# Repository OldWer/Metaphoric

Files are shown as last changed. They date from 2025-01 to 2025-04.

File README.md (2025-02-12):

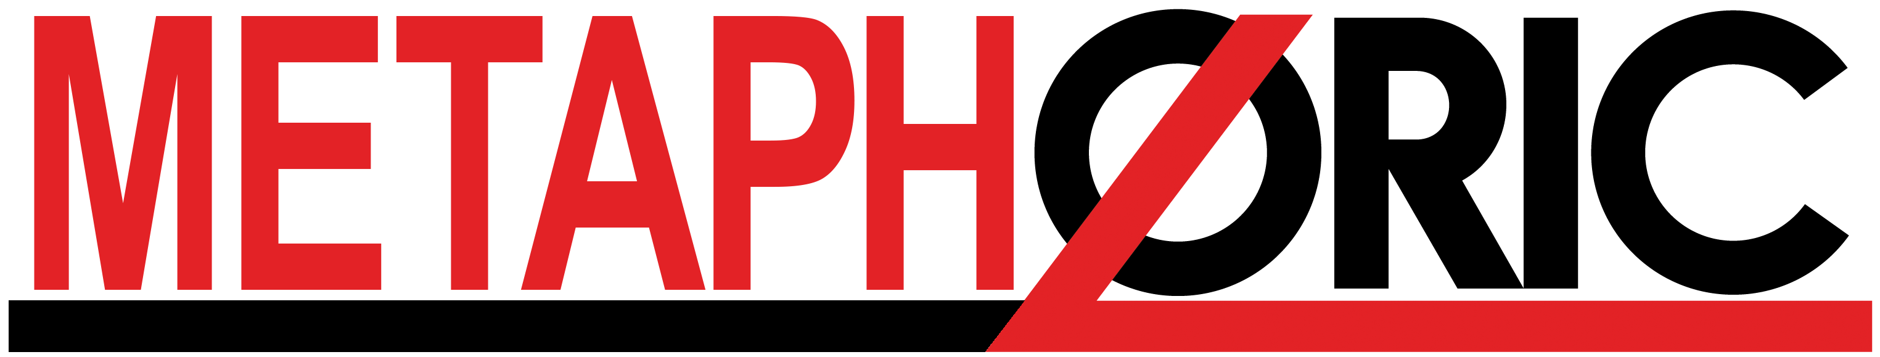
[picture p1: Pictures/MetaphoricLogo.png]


# Metaphoric - an enhanced Oric clone
Metaphoric is an Oric clone with the memory subsystem based on the OriClone-1 project and some additional features:
* Composite video output (RCA socket)
* TRRS audio-video socket for connecting "jack to 3xRCA" cable
* Footprints for both original AY-3-8912 chips and for (much cheaper) AY-3-8910 chips (or other 40-pin clones)
* Ability to use 7905 or 7805 power regulator and also to power the Metaphoric using an external +5V power supply
* Two Atari-standard joystick ports on the keyboard PCB — one is an IJK „Stingy” port, the other is a cursors+space joystick for games that do not support IJK but are controlled with cursors or make it possible to redefine the keys.
* Easily accessible RESET and NMI buttons on top of the keyboard.
* Easily accessible switches for changing the ROM between Oric-1 and Oric Atmos and for disabling the IJK interface (it may interfere with the operation of printer port and it can also corrupt sound in games that do not support IJK, e.g. Manic Miner)
* Automatic hardware V-sync hack - original Orics did not have any way of checking the vertical sync signal, which made it difficult to write games without flickering sprites, so somebody came up with the idea of connecting video sync signal to tape in using an external cable and synchronizing games/demos in that way. Metaphoric has a transistor that connects sync out to tape in when the tape relay is inactive and disconnects it when the relay is active (to allow loading from tape).

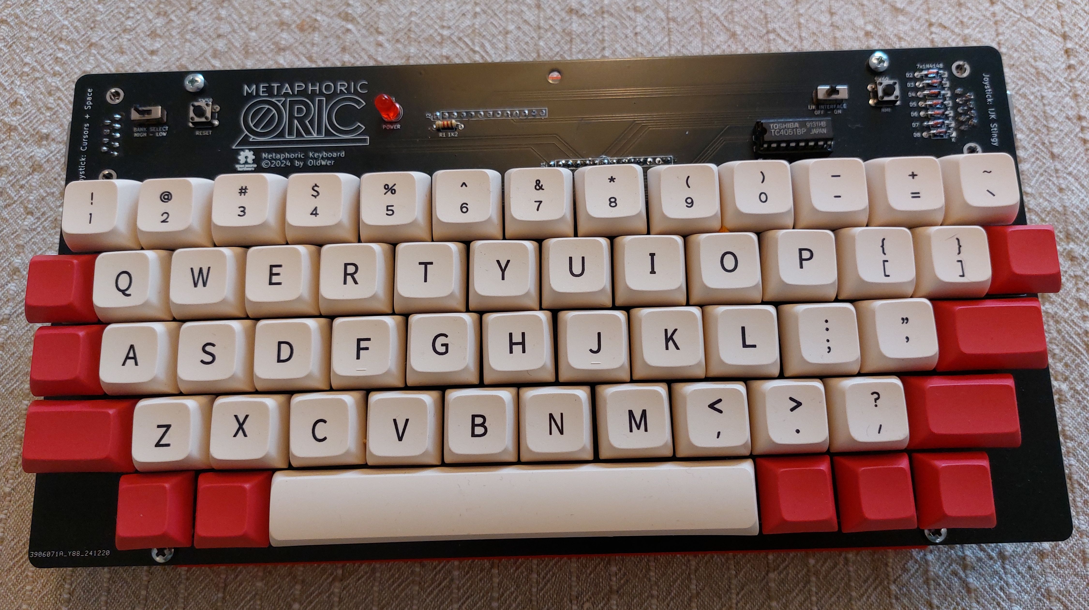
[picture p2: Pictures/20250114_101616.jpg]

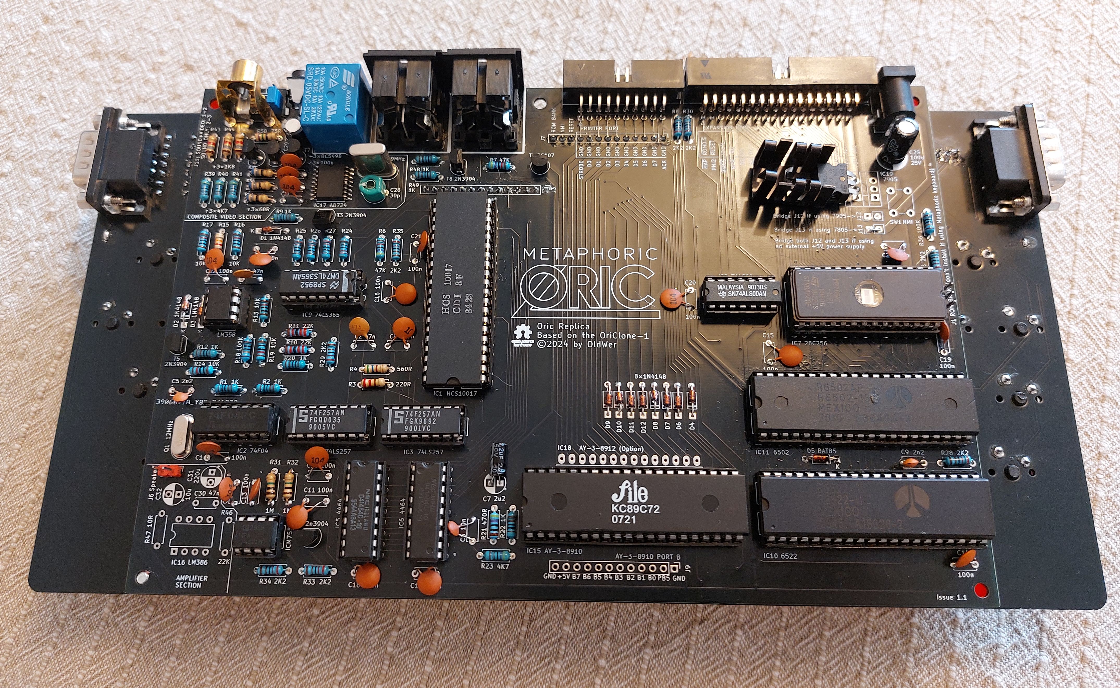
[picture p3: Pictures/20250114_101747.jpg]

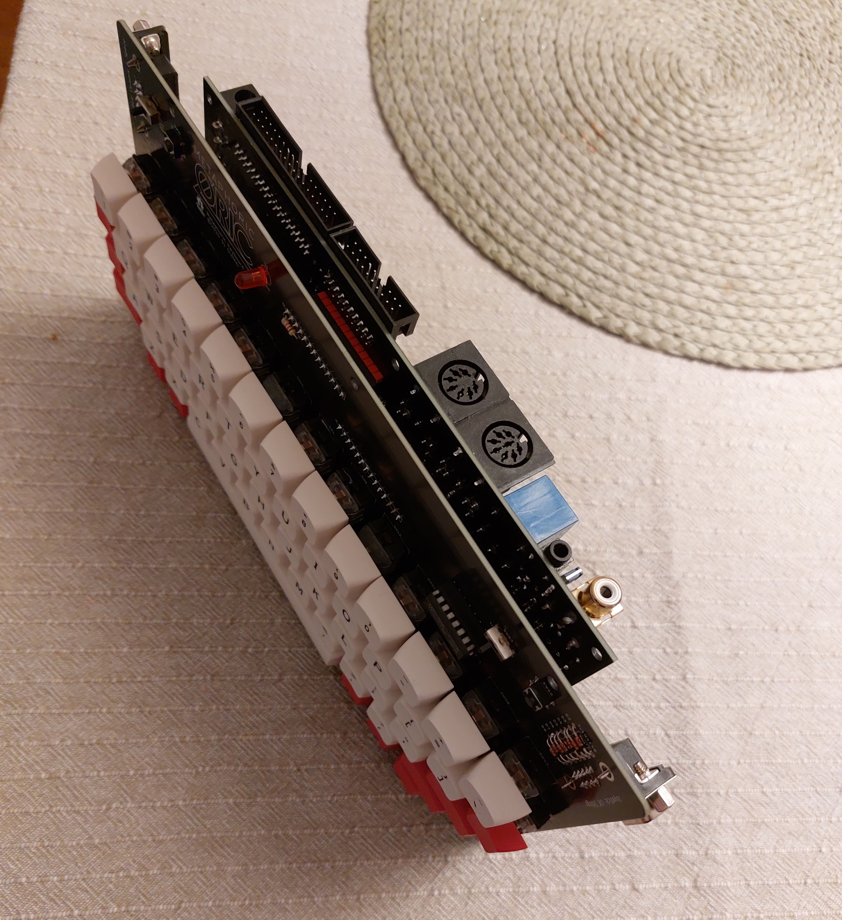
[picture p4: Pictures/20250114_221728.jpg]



# Building the Metaphoric
<b>Note</b>: The main PCB fits in the original Oric-1/Atmos case (the keyboard PCB <i>does not</i>!). If you would like to use the main PCB with the original keyboard and case, do not install J10 (TRRS socket) and J7 (auxiliary connector that supports the extra switches, buttons and ports on the keyboard). Also all the chips near the bottom of the board - IC10, IC15/18, IC5, IC6, IC12 and IC16 - cannot be socketed and must be soldered directly to the board, or the original case won't close.

The repository contains two directories with KiCAD projects for the main PCB and the keyboard PCB. The bill of materials is available in <i>BOM.*</i> files in the respective directories (in <i>.csv</i>, <i>.xlsx</i> and <i>.PDF</i> formats). In the <i>gerbers</i> subdirectories there are gerber files ready for manufacturing (I used recommended JLCPCB settings when exporting the gerbers). In the main PCB's <i>STL</i> subdirectory there are 3D models for a simple case and also for a spacer which you can print in 5 copies and which is used to separate the two boards. In the keyboard's <i>STL</i> subdirectory there is a 3D model for a holder that fits in the big square holes in the keyboard PCB and holds a typical space key stabilizer.

<b>Note about ROMs</b>: You can use either a 28c128 EEPROM or a 27c512 EPROM, appropriate <i>.bin</i> files are in the <i>MetaphoricV2/ROM</i> subdirectory. 27c256 EPROM would be enough to store two 16K banks with Oric-1 and Atmos ROMs, but it has different pinout - it would still work, but it wouldn't be possible to select ROM banks and only the high bank would be available. However, if you happen to have only 27c256 EPROMs, you may cut the trace between the ROM pins 27 and 28 (on the back of the PCB) and run a bodge wire from ROM pin 1 to ROM pin 27; this should make it possible to use a 27c256 EPROM with switchable banks.

Most of the build is pretty self-explanatory, as all the components are described on the PCB. The things to watch for, in no particular order, are as follows:
1. You can omit all the parts in the 'COMPOSITE VIDEO SECTION' if you're only planning to use the RGB output (well, maybe except for the TRRS socket, which can also be used to output audio, and the J11 header). The file 'RGB_Scart_Tape.pdf' shows how to build a SCART cable, and this is definitely the recommended way of using an Oric, original or cloned.
2. Next to the composite RCA socket there is the J11 header. You can put jumper on pins 2-3 to use the nearby 3.5mm TRRS socket as an audio/video video out; there are ready-made 3.5mm jack-3 x RCA cables which you can use to output video and sound. Or you can put a jumper on pins 1-2 to use the TRRS socket as a regular 3.5mm stereo sound out, useful for connecting the Oric to a stereo system or an external speaker. 
3. You can omit all the parts in the "AMPLIFIER SECTION" if you're not going to use the internal speaker. Again, highly recommended to skip these components, they were only added for the sake of completeness, the sound quality is pretty terrible with the internal speaker and in some games there is no way to turn it off or to control volume.
4. The J1 header on the right side of the board can be used to switch the ROM bank, but if the main PCB is connected to the Metaphoric keyboard PCB, it <b>should not</b> be jumpered. There is a switch on the keyboard PCB that does the same, and because switching the banks means connecting either ground or +5V to one of the ROM address lines, if you leave the J1 jumpered and then connect the Metaphoric keyboard, in one of the two switch positions the +5V will get shorted to ground. So you can install the J1 e.g. for testing the main PCB or if it is to be used in the original Oric case, but before you connect it to the Metaphoric keyboard, <b>remember to take the jumper off!</b>
5. In the power section in the top right corner of the main PCB there are footprints for either 7905 or 7805 regulator. The 7905 is recommended only if you intend to use the Metaphoric with original Oric accessories, such as floppy drives (or modern recreations, such as Cumana Reborn). Modern solutions, such as Erebus or Loci, can be used with 7805 or an external +5V power supply. Depending on which regulator you choose, you must close one of the J12/J13 bridges. Close J12 (using a piece of wire, a diode leg will do) if using 7905, close J13 if using 7805. It is also possible to connect an external power switch across one of those bridges and use it to power the Metaphoric on and off. Another way to power the Metaphoric is to close both J12 and J13 bridges (without installing any regulator!) and use external +5V power supply, <b>center positive</b> (ground on the sleeve, +5V on the tip). I personally prefer this solution (no heat generated inside) and just use a USB power supply. If you decide to use a regulator, power the Metaphoric with a +9V power supply, <b>center positive</b>.
9. The main PCB and the keyboard PCB are connected using two pin headers - J3 and J7 on the main PCB, J1 and J2 on the keyboard PCB. Two male pin headers must be installed on the back of the main PCB, two female headers on the back of the keyboard PCB, and then the two boards must be connected back to back:
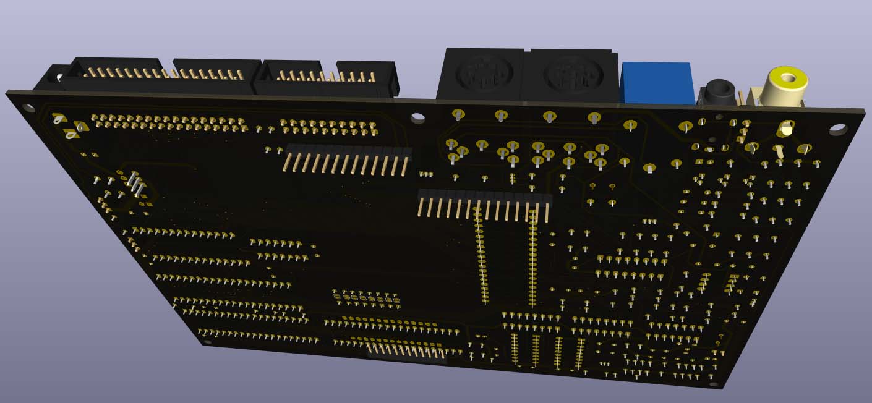
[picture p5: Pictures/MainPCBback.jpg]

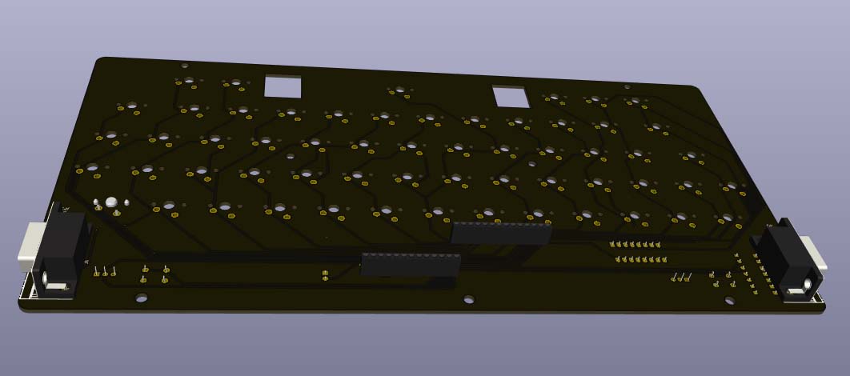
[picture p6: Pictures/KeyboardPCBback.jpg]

Then you should put 3D printed spacers between the two boards where the holes are and screw the boards to the case using M3x16 or M3x18 screws.

10. As for the keyboard, the joystick ports must be soldered on the back side of the PCB, like so:
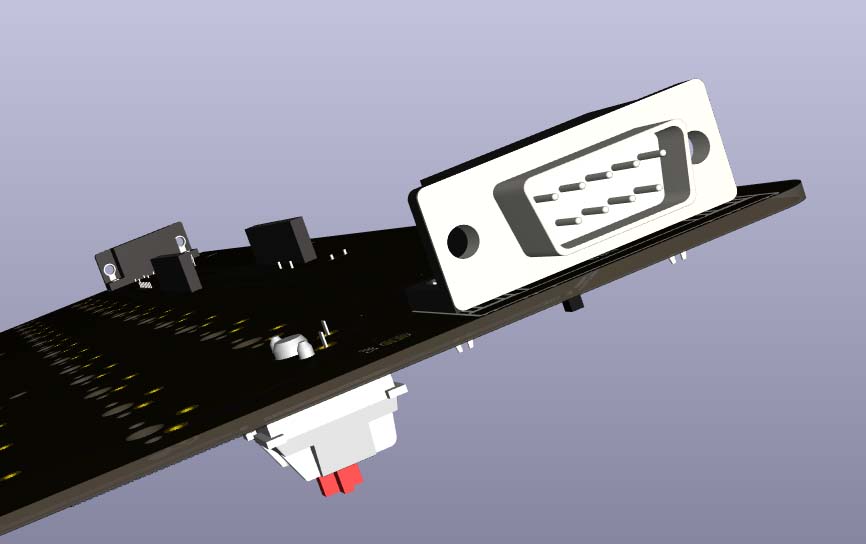
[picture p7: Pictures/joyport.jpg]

11. There are also solder jumpers JP2 and JP3 that can be used to configure additional joystick buttons (as in eg. MSX, Amstrad CPC or Sega Master System/Amiga joysticks). There are some powered joysticks (e.g. with an autofire function) which are usually powered from the pin 7 of the DB9 port, and it probably wouldn't be a good idea to power them intermittently from the outputs of the VIA or the AY chip. If you'd like to use additional buttons, see the note in the keyboard schematic.
12. The spacebar stabilizer holder must be printed once in normal orientation (left) and once mirrored (right), because it is not exactly symmetrical. Then the holders must be pushed into the big square holes in the kyeboard PCB (some light sanding may be necessary), and finally the stabilizer itself must be glued to the holders with a tiny amount of glue (so as not to glue together the moving plastic parts).
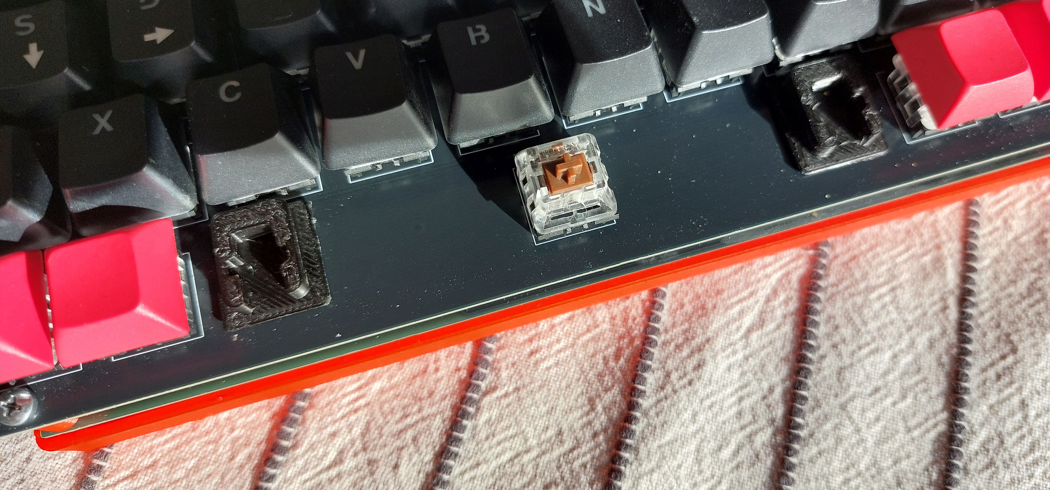
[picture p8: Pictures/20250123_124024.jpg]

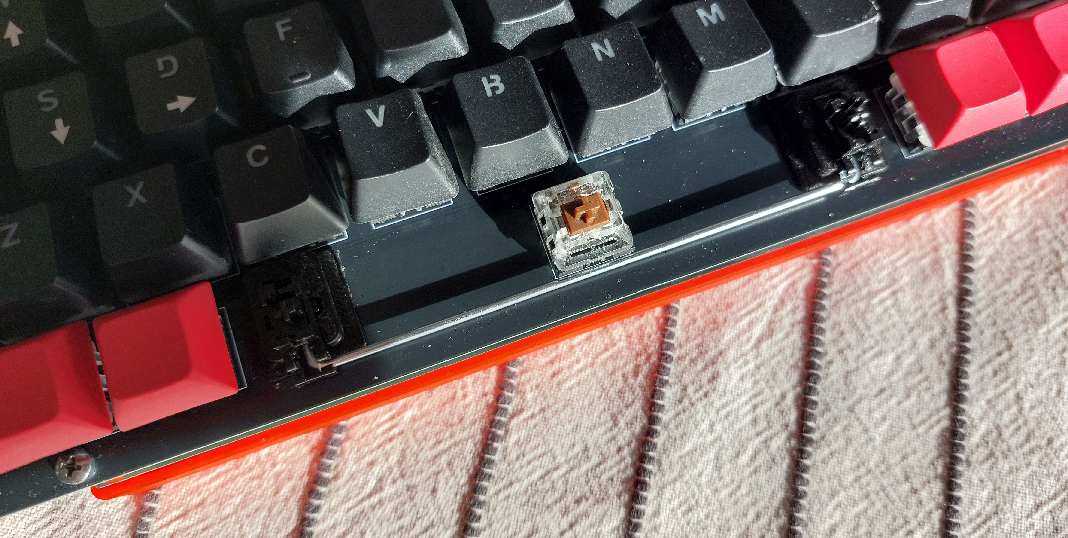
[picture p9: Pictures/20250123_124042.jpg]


If in doubt, open the relevant KiCAD PCB file and go to the 3D viewer; I've added 3D models for all the parts, creating some that I could not find anywhere, and you can check exactly how everything should look like.

If you have any questions, write to me at oldwer@op.pl, I will be happy to help.

Good luck soldering your own Oric!

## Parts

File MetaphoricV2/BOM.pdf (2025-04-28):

Reference | Value | Footprint | Qty | Notes
CAPACITORS | | | | DIP SOCKETS
C1;C3;C8;C10;C11;C12;C13;C14;C15;C16;
C17;C18;C19;C20;C21;C22;C23;C24;C26;C27 | 100n | Ceramic capacitor | 20 | DIP14 | 2
C2;C4;C30 | 47n | Ceramic capacitor | 3 | DIP16 | 3
C5;C9 | 2.2n | Ceramic capacitor | 2 | DIP18 | 2
C6 | 10n | Ceramic capacitor | 1 | DIP28 | 1
C7 | 2.2u | Electrolytic capacitor | 1 | DIP40 | 4
C25 | 100u 25v | Electrolytic capacitor | 1 | DIP8 | 3
C28 | 30p | Trimmer | 1
C29;C31 | 220u | Electrolytic capacitor | 2
C32 | 10u | Electrolytic capacitor | 1
DIODES
D1;D2;D3;D4;D6;D7;D8;D9;D10;D11;D12 | 1N4148 | DO-35 | 11
D5 | BAT85 | DO-35 | 1
INTEGRATED CIRCUITS
IC2 | 74F04 | DIP14 | 1
IC8 | 74LS00 | DIP14 | 1
IC3;IC4 | 74LS257 | DIP16 | 2
IC9 | 74LS365 | DIP16 | 1
IC5;IC6 | MEMORY 4464 | DIP18 | 2
IC7 | 28C256 | DIP28 | 1
IC1 | HCS10017 | DIP40 | 1
IC10 | VIA 6522 | DIP40 | 1
IC11 | CPU 6502 | DIP40 | 1
IC15 | AY-3-8910 | DIP40 | 1
IC12 | ICM7555xP | DIP8 | 1
IC14 | LM358 | DIP8 | 1
IC16 | LM386 | DIP8 | 1
IC17 | AD724 | SOIC-16W | 1
VOLTAGE REGULATOR
IC13/IC19 | L7805/L7905 | TO-220-3 | 1
CONNECTORS

J1;J11 | Conn_01x03 | PinHeader_1x03 | 2 (35 pins total)
J2 | DIN-7 | DIN7 Socket | 1 Tape
SK1 | DIN-8 | DIN8 Socket | 1 Video
J3 | Conn_01x14 | PinHeader_1x14 | 1 Keyboard
J4 | Barrel_Jack | Barrel Jack | 1 Power
J5 | Conn_Coaxial | RCA Socket | 1 Composite
J6 | Conn_01x02 | PinHeader_1x02 | 1 Speaker
J7 | Joystick | PinHeader_1x13 | 1 Keyboard 2
J9 | Conn_01x12 | PinHeader_1x12 | 1 Unpopulated
J10 | AudioJack4 | TRRS Socket PJ-322 | 1 Audio/Video
SV1 | Printer | IDC-Header_2x10 | 1
SV2 | Expansion | IDC-Header_2x17 | 1
RELAY
K1 | SRD-05VDC-SL-C Relay | 1
CRYSTALS
Q1 | 12MHz | Crystal_HC49-U | 1
Q2 | 4.433619 MHz | Crystal_HC49-U | 1
RESISTORS
R1;R2;R9;R12;R20;R22;R48;R49 | 1k | Resistor | 8
R3 | 220r | Resistor | 1
R4 | 560r | Resistor | 1
R5;R8;R28;R29;R30;R33;R34;R35 | 2k2 | Resistor | 8
R6;R7 | 47k | Resistor | 2
R10;R11;R46 | 22k | Resistor | 3
R13;R14;R16;R17;R19 | 10k | Resistor | 5
R15 | 12k | Resistor | 1
R18;R36 | 100k | Resistor | 2
R21 | 470r | Resistor | 1
R23;R39;R40;R41 | 4k7 | Resistor | 4
R24;R25;R26;R27 | 220r | Resistor | 4
R31;R32 | 1M | Resistor | 2
R37;R38;R42 | 68r | Resistor | 3
R43;R44;R45 | 1k8 | Resistor | 3

R47 | 10r | Resistor

1
R58 | 75r | Resistor

1
BUTTON
SW1 | SW_Push | Tact Switch

1
TRANSISTORS
T1;T3;T5;T8 | 2N3904 | Transistor

4
T2 | BS170 | Transistor

1
T4;T6;T7 | BC549B | Transistor

3

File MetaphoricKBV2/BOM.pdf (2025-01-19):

Reference | Value | Footprint | Qty
DIODES
D1 | LED | LED 5.0mm | 1
D2;D3;D4;D5;D6;D7;D8 1N4148 | DO-35 | 7
CONNECTORS
J1 | Conn_01x14 PinHeader_1x14 Female | 1
J2 | Joystick | PinHeader_1x13 Female | 1
J3;J4 | DB9 | DB-9 | 2
RESISTOR
R1 | 1K2 | Resistor | 1
KEY SWITCHES
SW1-SW58 | Cherry MX | 58
SWITCHES
SW59 | RESET | Tact Switch | 1
SW60 | NMI | Tact Switch | 1
SW62 | BANKSEL | Switch 3pin | 1
SW63 | IJK DISABLE Switch 3pin | 1
IC | | | DIP Socket
U1 | 4051 DIP-16 | 1 | DIP-16 | 1

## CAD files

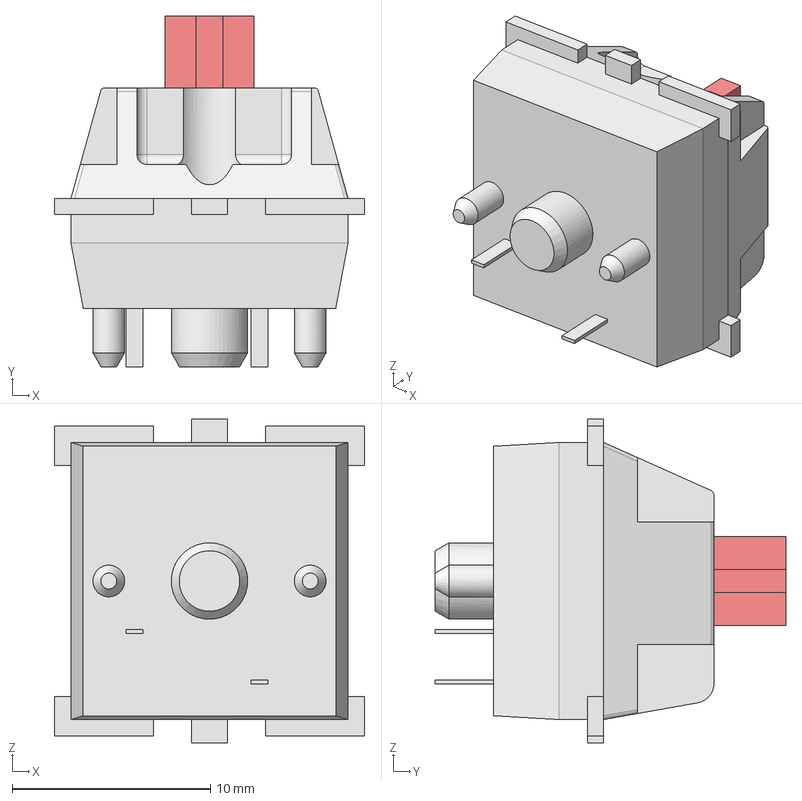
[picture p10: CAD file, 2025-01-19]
MetaphoricKBV2/3DModels/switchw.step
15.6 x 17.7 x 16.3 mm

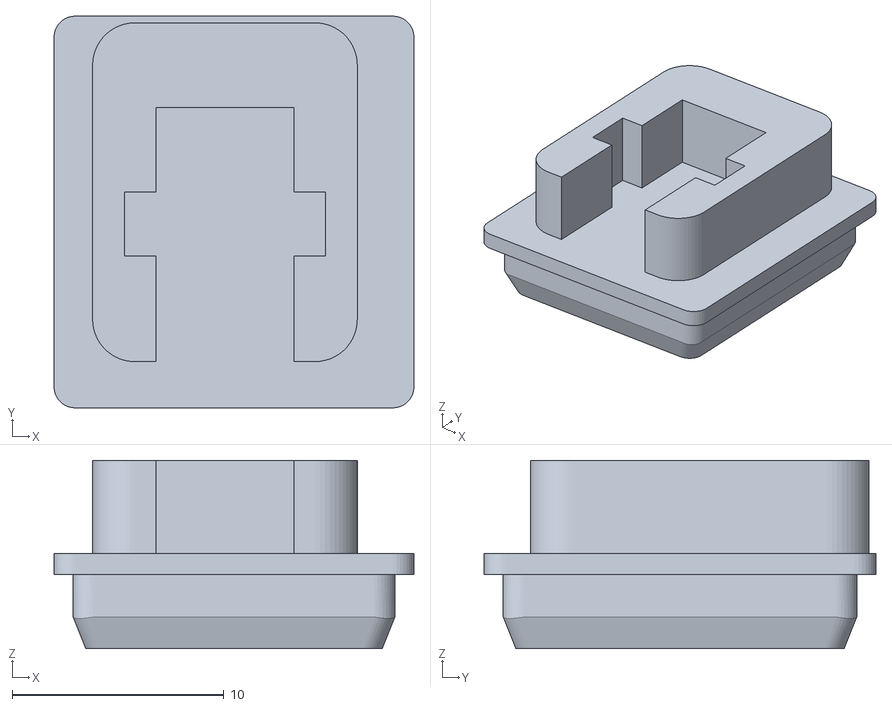
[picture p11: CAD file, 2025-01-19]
MetaphoricKBV2/STL/SpBarHld.stl
17.0 x 18.5 x 8.90

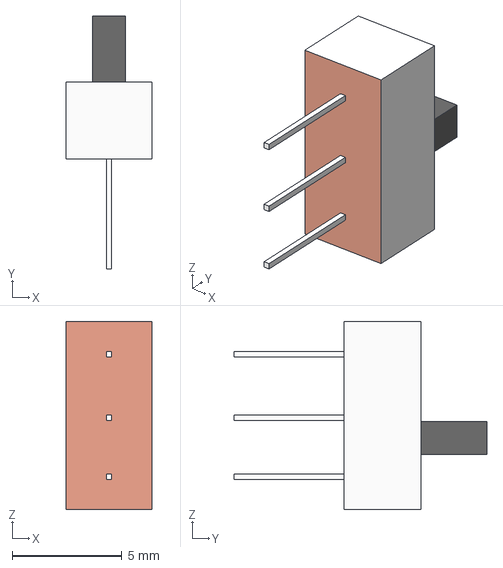
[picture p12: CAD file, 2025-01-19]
MetaphoricKBV2/switch small.stp
3.90 x 11.5 x 8.55 mm

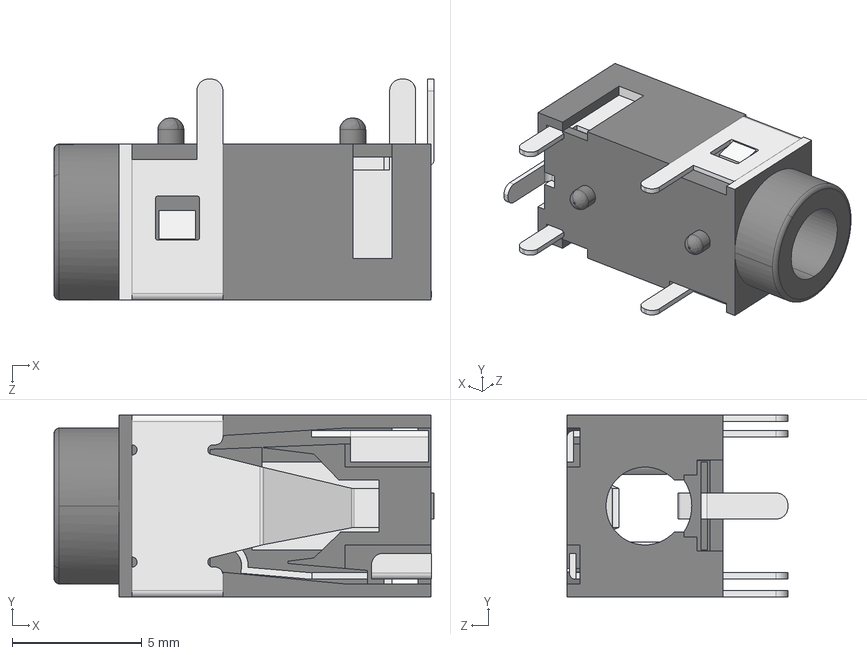
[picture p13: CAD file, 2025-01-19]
MetaphoricV2/3DModels/PJ-322.step
14.6 x 7.00 x 8.50 mm

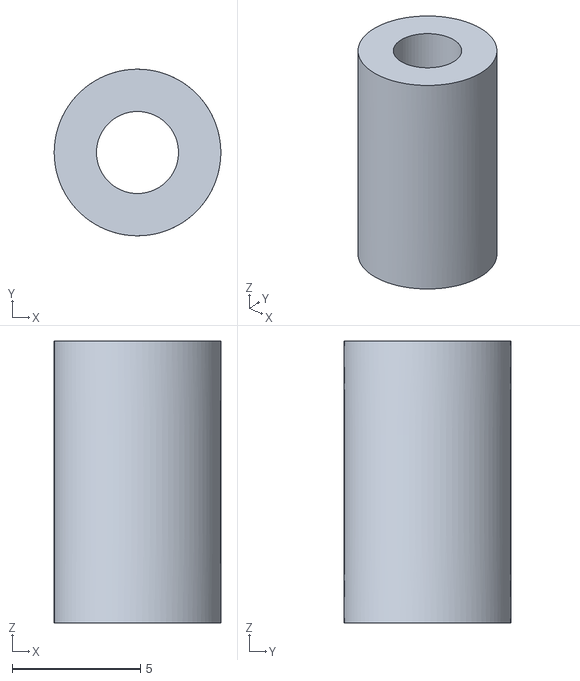
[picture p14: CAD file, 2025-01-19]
MetaphoricV2/STL/distance.stl
6.50 x 6.50 x 11.0

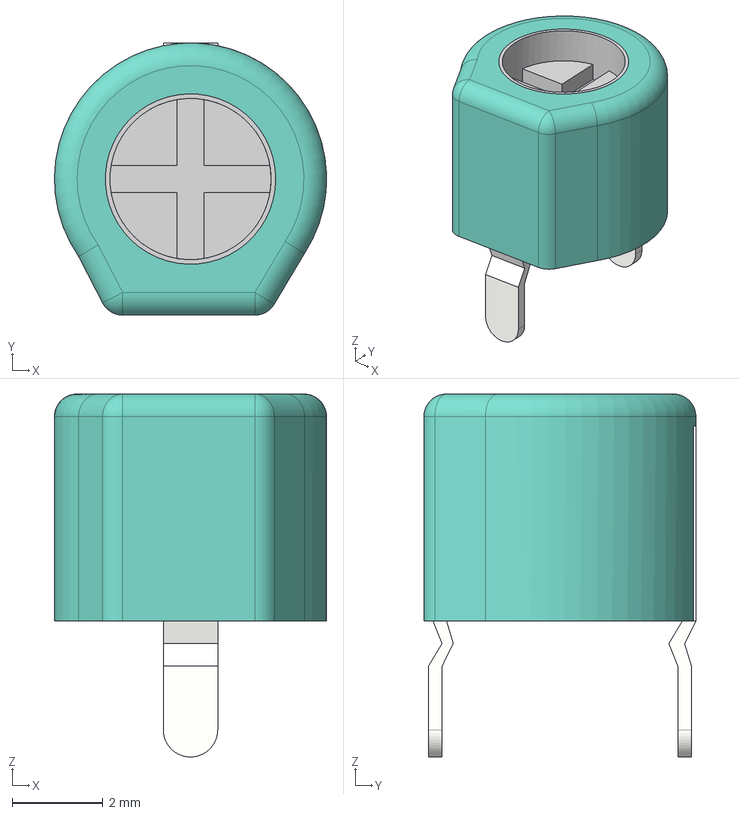
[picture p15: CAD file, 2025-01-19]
MetaphoricV2/3DModels/30p.step
6.00 x 6.00 x 8.00 mm

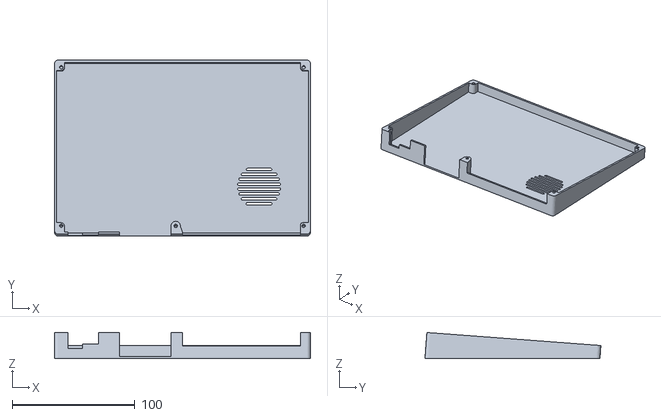
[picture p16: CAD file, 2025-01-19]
MetaphoricV2/STL/metaphoric.stl
208.1 x 143.0 x 21.1

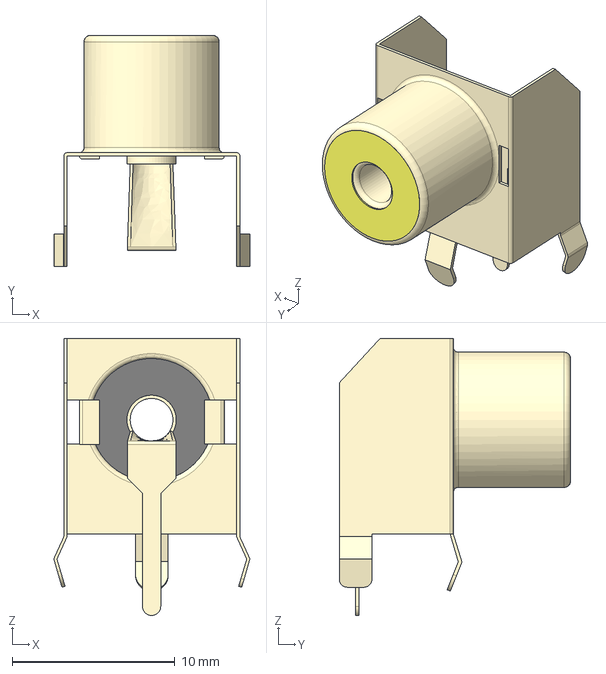
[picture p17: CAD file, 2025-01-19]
MetaphoricV2/3DModels/RCA_yellow.step
12.0 x 14.2 x 17.0 mm

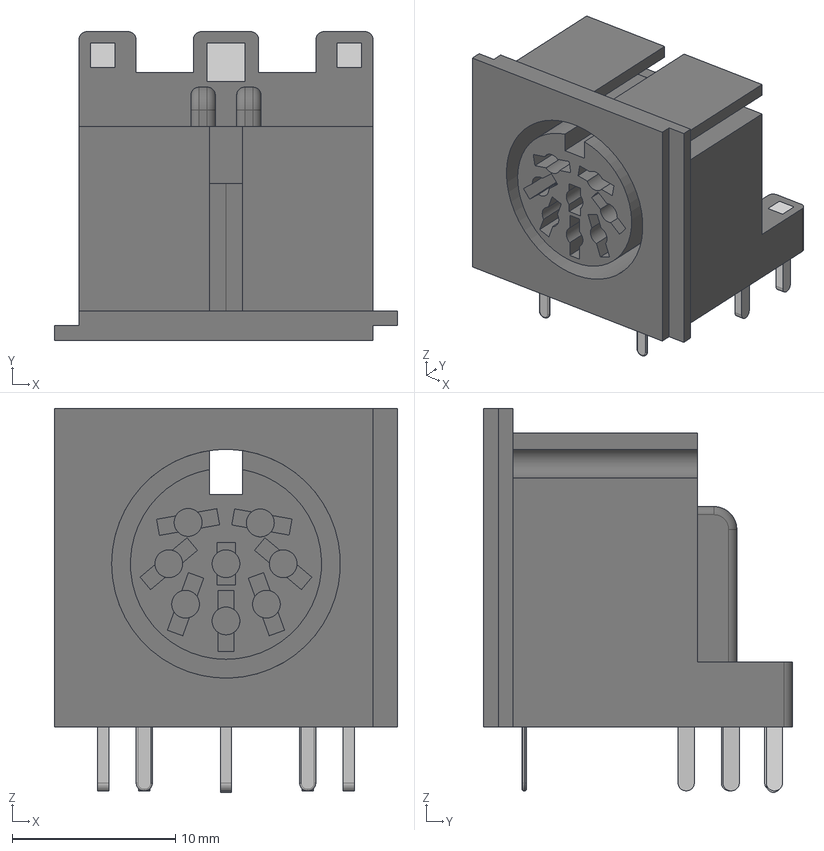
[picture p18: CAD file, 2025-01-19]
MetaphoricV2/3DModels/din-8-jack.step
21.0 x 18.9 x 23.5 mm
front-pin2
front-pin1

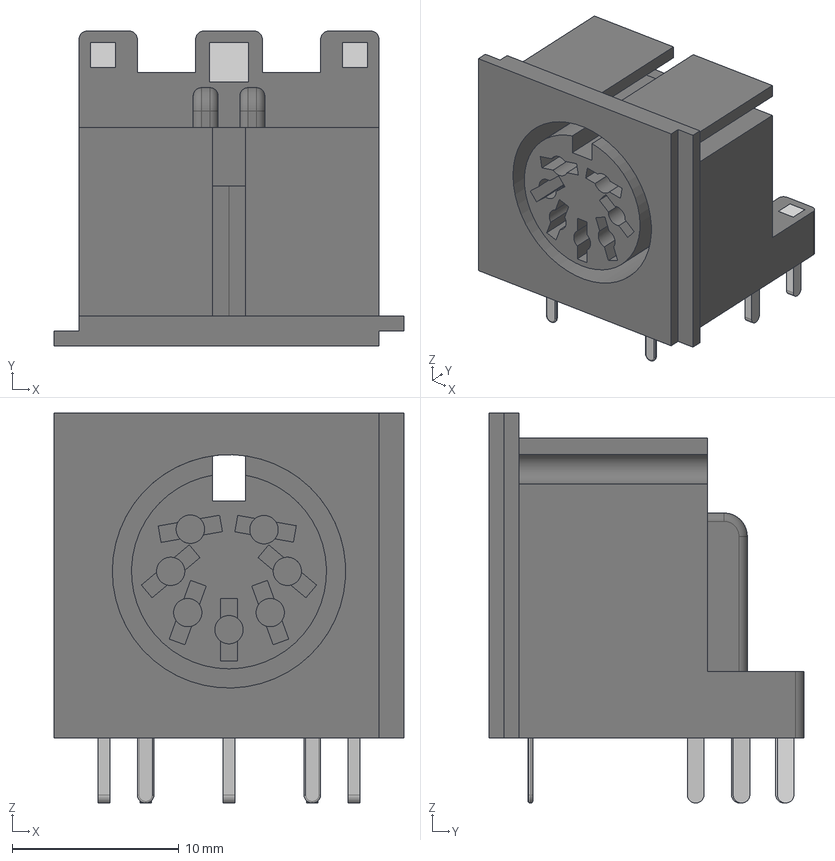
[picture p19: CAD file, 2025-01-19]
MetaphoricV2/3DModels/din-7-jack.step
21.0 x 18.9 x 23.4 mm
front-pin2
front-pin1

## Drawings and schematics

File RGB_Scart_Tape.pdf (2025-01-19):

## Looking into the socket (or at the plug’s solder side)

# VIDEO OUT

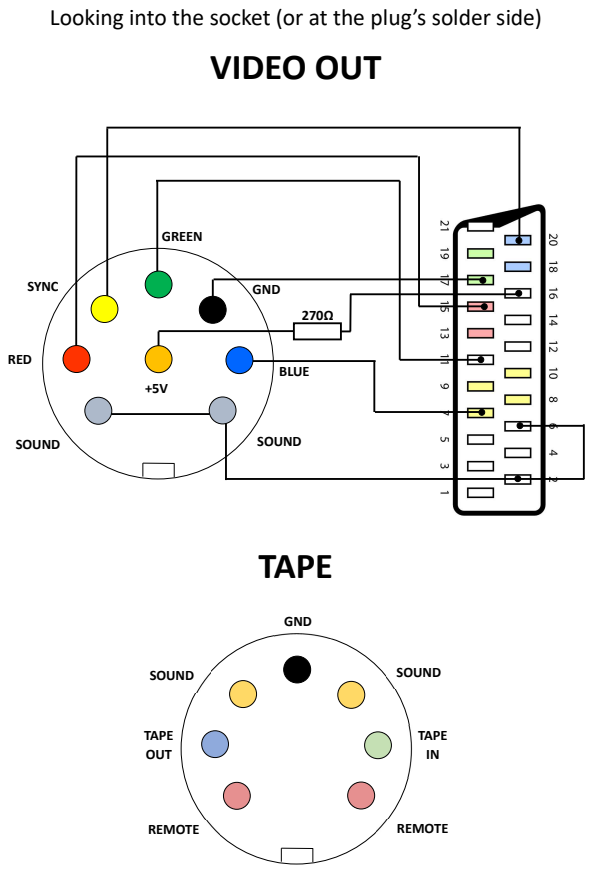
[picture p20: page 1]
TAPE; TAPE OUT; GND; SOUND; TAPE IN; REMOTE; GREEN; SYNC; RED; BLUE

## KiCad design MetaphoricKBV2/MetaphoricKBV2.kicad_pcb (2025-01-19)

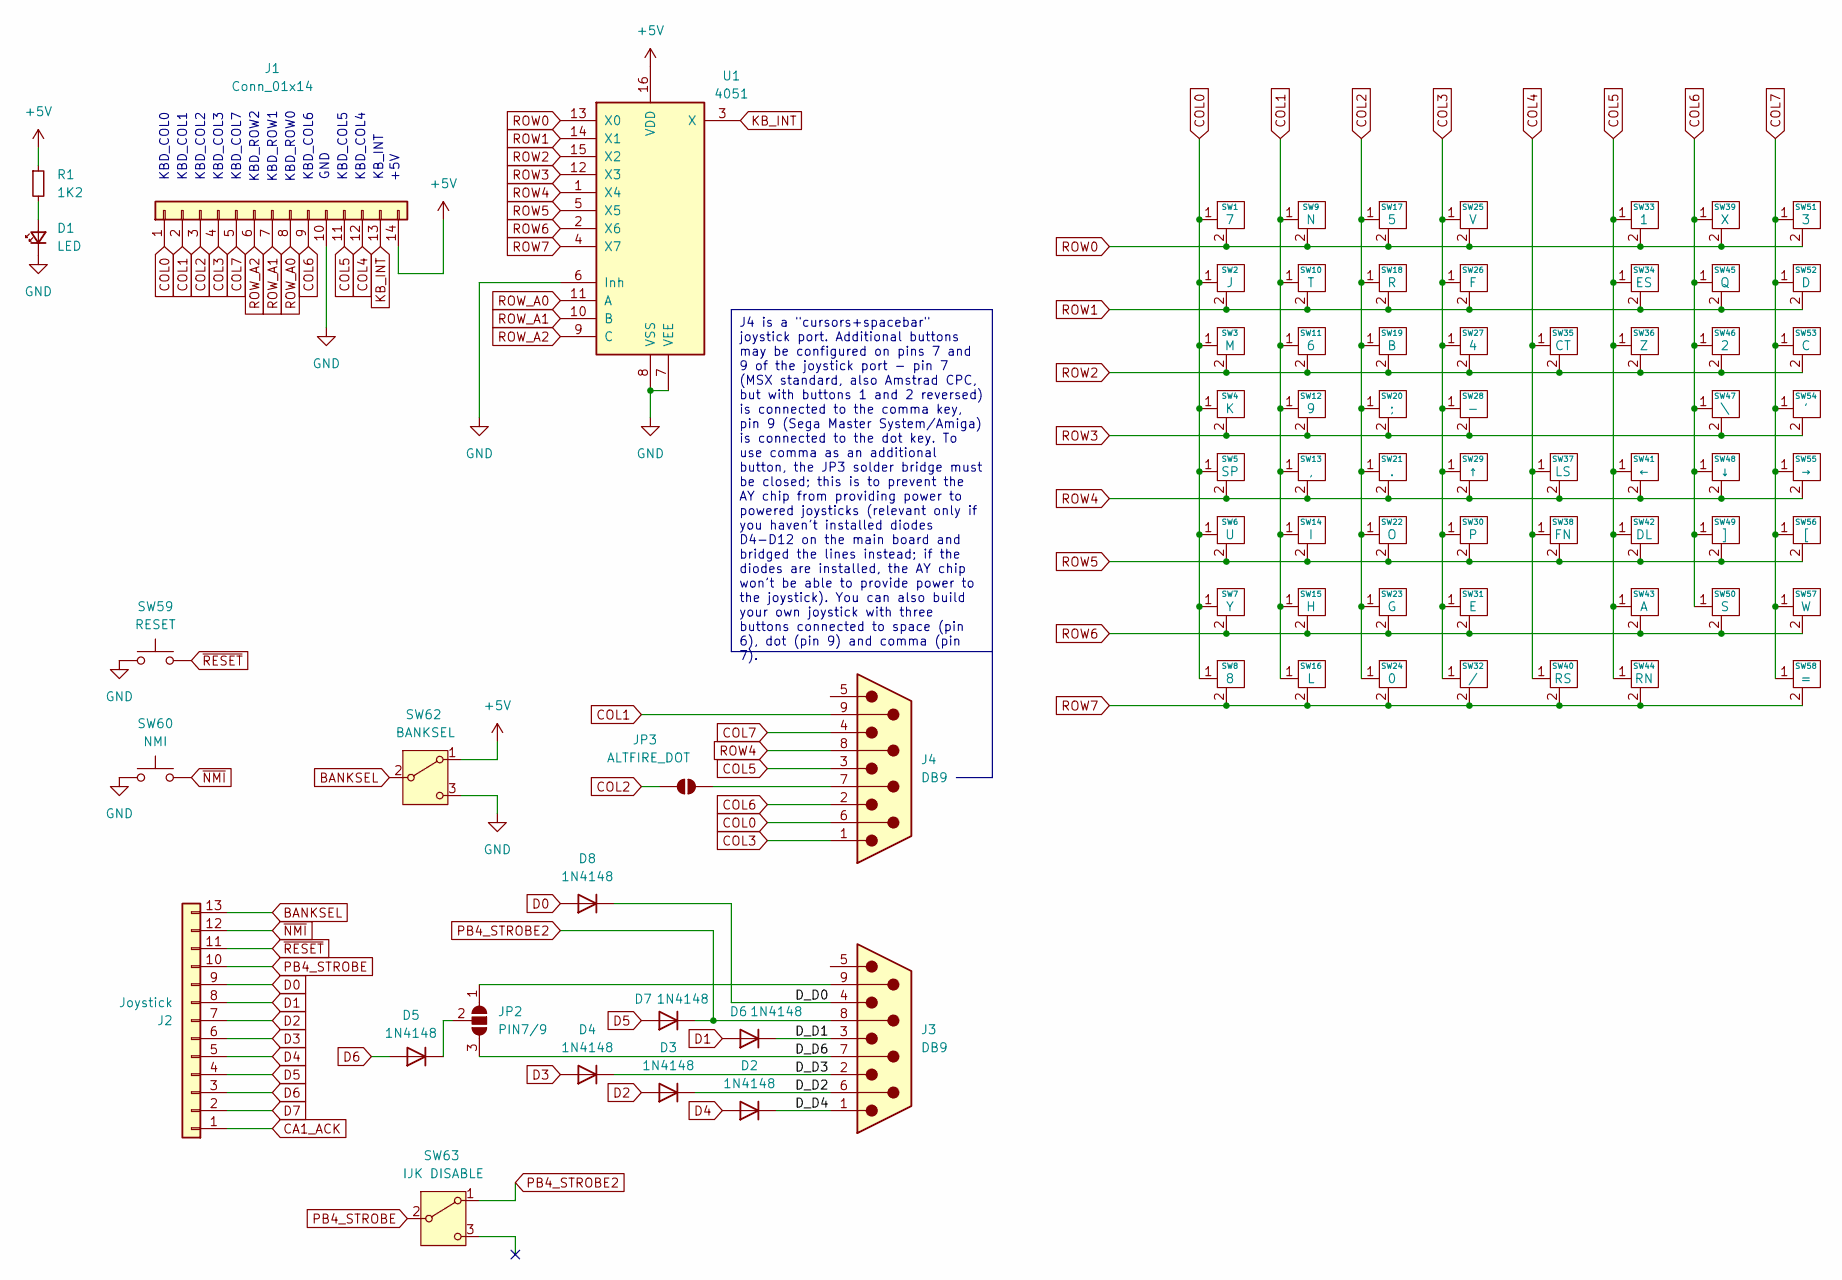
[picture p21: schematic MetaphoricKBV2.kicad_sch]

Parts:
D1: LED; LED_D5.0mm
D2, D3, D4, D5, D6, D7, D8: 1N4148; D_DO-35_SOD27_P7.62mm_Horizontal
J1: Conn_01x14; PinHeader_1x14_P2.54mm_Vertical
J2: Joystick; PinHeader_1x13_P2.54mm_Vertical
J3, J4: DB9; DB_9M
JP2: PIN7/9; SolderJumper-3_P1.3mm_Open_RoundedPad1.0x1.5mm
JP3: ALTFIRE_DOT; SolderJumper-2_P1.3mm_Open_RoundedPad1.0x1.5mm
R1: 1K2; R_Axial_DIN0204_L3.6mm_D1.6mm_P7.62mm_Horizontal
SW1: 7; SW_Cherry_MX_PCB_1.00u
SW2: J; SW_Cherry_MX_PCB_1.00u
SW3: M; SW_Cherry_MX_PCB_1.00u
SW4: K; SW_Cherry_MX_PCB_1.00u
SW5: SP; SW_Cherry_MX_PCB_6.25u
SW6: U; SW_Cherry_MX_PCB_1.00u
SW7: Y; SW_Cherry_MX_PCB_1.00u
SW8: 8; SW_Cherry_MX_PCB_1.00u
SW9: N; SW_Cherry_MX_PCB_1.00u
SW10: T; SW_Cherry_MX_PCB_1.00u
SW11: 6; SW_Cherry_MX_PCB_1.00u
SW12: 9; SW_Cherry_MX_PCB_1.00u
SW13: ,; SW_Cherry_MX_PCB_1.00u
SW14: I; SW_Cherry_MX_PCB_1.00u
SW15: H; SW_Cherry_MX_PCB_1.00u
SW16: L; SW_Cherry_MX_PCB_1.00u
SW17: 5; SW_Cherry_MX_PCB_1.00u
SW18: R; SW_Cherry_MX_PCB_1.00u
SW19: B; SW_Cherry_MX_PCB_1.00u
SW20: ;; SW_Cherry_MX_PCB_1.00u
SW21: .; SW_Cherry_MX_PCB_1.00u
SW22: O; SW_Cherry_MX_PCB_1.00u
SW23: G; SW_Cherry_MX_PCB_1.00u
SW24: 0; SW_Cherry_MX_PCB_1.00u
SW25: V; SW_Cherry_MX_PCB_1.00u
SW26: F; SW_Cherry_MX_PCB_1.00u
SW27: 4; SW_Cherry_MX_PCB_1.00u
SW28: -; SW_Cherry_MX_PCB_1.00u
SW29: ↑; SW_Cherry_MX_PCB_1.00u
SW30: P; SW_Cherry_MX_PCB_1.00u
SW31: E; SW_Cherry_MX_PCB_1.00u
SW32: /; SW_Cherry_MX_PCB_1.00u
SW33: 1; SW_Cherry_MX_PCB_1.00u
SW34: ES; SW_Cherry_MX_PCB_1.00u
SW35: CT; SW_Cherry_MX_PCB_1.00u
SW36: Z; SW_Cherry_MX_PCB_1.00u
SW37: LS; SW_Cherry_MX_PCB_1.50u
SW38: FN; SW_Cherry_MX_PCB_1.00u
SW39: X; SW_Cherry_MX_PCB_1.00u
SW40: RS; SW_Cherry_MX_PCB_1.50u
SW41: ←; SW_Cherry_MX_PCB_1.00u
SW42: DL; SW_Cherry_MX_PCB_1.00u
SW43: A; SW_Cherry_MX_PCB_1.00u
SW44: RN; SW_Cherry_MX_PCB_1.50u
SW45: Q; SW_Cherry_MX_PCB_1.00u
SW46: 2; SW_Cherry_MX_PCB_1.00u
SW47: \; SW_Cherry_MX_PCB_1.00u
SW48: ↓; SW_Cherry_MX_PCB_1.00u
SW49: ]; SW_Cherry_MX_PCB_1.00u
SW50: S; SW_Cherry_MX_PCB_1.00u
SW51: 3; SW_Cherry_MX_PCB_1.00u
SW52: D; SW_Cherry_MX_PCB_1.00u
SW53: C; SW_Cherry_MX_PCB_1.00u
SW54: '; SW_Cherry_MX_PCB_1.00u
SW55: →; SW_Cherry_MX_PCB_1.00u
SW56: [; SW_Cherry_MX_PCB_1.00u
SW57: W; SW_Cherry_MX_PCB_1.00u
SW58: =; SW_Cherry_MX_PCB_1.00u
SW59: RESET; SW_PUSH_6mm
SW60: NMI; SW_PUSH_6mm
SW62: BANKSEL; PinHeader_1x03_P2.54mm_Vertical
SW63: IJK DISABLE; PinHeader_1x03_P2.54mm_Vertical
U1: 4051; DIP-16_W7.62mm_LongPads

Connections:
+5V: J1.14, R1.1, SW62.1 (A), U1.16 (VDD)
/D_D0: D8.1 (K), J3.4
/D_D1: D6.1 (K), J3.3
/D_D2: D3.1 (K), J3.6
/D_D3: D4.1 (K), J3.2
/D_D4: D2.1 (K), J3.1
/D_D6: J3.7, JP2.3 (B)
BANKSEL: J2.13, SW62.2 (B)
CA1_ACK: J2.1
COL0: J1.1, J4.6, SW1.1, SW2.1, SW3.1, SW4.1, SW5.1, SW6.1, SW7.1, SW8.1
COL1: J1.2, J4.9, SW9.1, SW10.1, SW11.1, SW12.1, SW13.1, SW14.1, SW15.1, SW16.1
COL2: J1.3, JP3.1 (A), SW17.1, SW18.1, SW19.1, SW20.1, SW21.1, SW22.1, SW23.1, SW24.1
COL3: J1.4, J4.1, SW25.1, SW26.1, SW27.1, SW28.1, SW29.1, SW30.1, SW31.1, SW32.1
COL4: J1.12, SW35.1, SW37.1, SW38.1, SW40.1
COL5: J1.11, J4.3, SW33.1, SW34.1, SW36.1, SW41.1, SW42.1, SW43.1, SW44.1
COL6: J1.9, J4.2, SW39.1, SW45.1, SW46.1, SW47.1, SW48.1, SW49.1, SW50.1
COL7: J1.5, J4.4, SW51.1, SW52.1, SW53.1, SW54.1, SW55.1, SW56.1, SW57.1, SW58.1
D0: D8.2 (A), J2.9
D1: D6.2 (A), J2.8
D2: D3.2 (A), J2.7
D3: D4.2 (A), J2.6
D4: D2.2 (A), J2.5
D5: D7.2 (A), J2.4
D6: D5.2 (A), J2.3
D7: J2.2
GND: D1.1 (K), J1.10, SW59.1, SW60.1, SW62.3 (C), U1.6 (Inh), U1.7 (VEE), U1.8 (VSS)
KB_INT: J1.13, U1.3 (X)
unnamed: D1.2 (A), R1.2
unnamed: D5.1 (K), JP2.2 (C)
unnamed: J3.9, JP2.1 (A)
unnamed: J4.7, JP3.2 (B)
PB4_STROBE: J2.10, SW63.2 (B)
PB4_STROBE2: D7.1 (K), J3.8, SW63.1 (A)
ROW0: SW1.2, SW9.2, SW17.2, SW25.2, SW33.2, SW39.2, SW51.2, U1.13 (X0)
ROW1: SW2.2, SW10.2, SW18.2, SW26.2, SW34.2, SW45.2, SW52.2, U1.14 (X1)
ROW2: SW3.2, SW11.2, SW19.2, SW27.2, SW35.2, SW36.2, SW46.2, SW53.2, U1.15 (X2)
ROW3: SW4.2, SW12.2, SW20.2, SW28.2, SW47.2, SW54.2, U1.12 (X3)
ROW4: J4.8, SW5.2, SW13.2, SW21.2, SW29.2, SW37.2, SW41.2, SW48.2, SW55.2, U1.1 (X4)
ROW5: SW6.2, SW14.2, SW22.2, SW30.2, SW38.2, SW42.2, SW49.2, SW56.2, U1.5 (X5)
ROW6: SW7.2, SW15.2, SW23.2, SW31.2, SW43.2, SW50.2, SW57.2, U1.2 (X6)
ROW7: SW8.2, SW16.2, SW24.2, SW32.2, SW40.2, SW44.2, SW58.2, U1.4 (X7)
ROW_A0: J1.8, U1.11 (A)
ROW_A1: J1.7, U1.10 (B)
ROW_A2: J1.6, U1.9 (C)
~NMI: J2.12, SW60.2
~RESET: J2.11, SW59.2

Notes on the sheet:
J4 is a "cursors+spacebar" joystick port. Additional buttons may be configured on pins 7 and 9 of the joystick port - pin 7 (MSX standard, also Amstrad CPC, but with buttons 1 and 2 reversed) is connected to the comma key, pin 9 (Sega Master System/Amiga) is connected to the dot key. To use comma a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
KBD_COL0
KBD_COL2
+5V
KBD_ROW1
KBD_COL6
KBD_COL7
KBD_COL3
KBD_COL4
KB_INT
KBD_COL1
KBD_COL5
KBD_ROW0
KBD_ROW2
GND

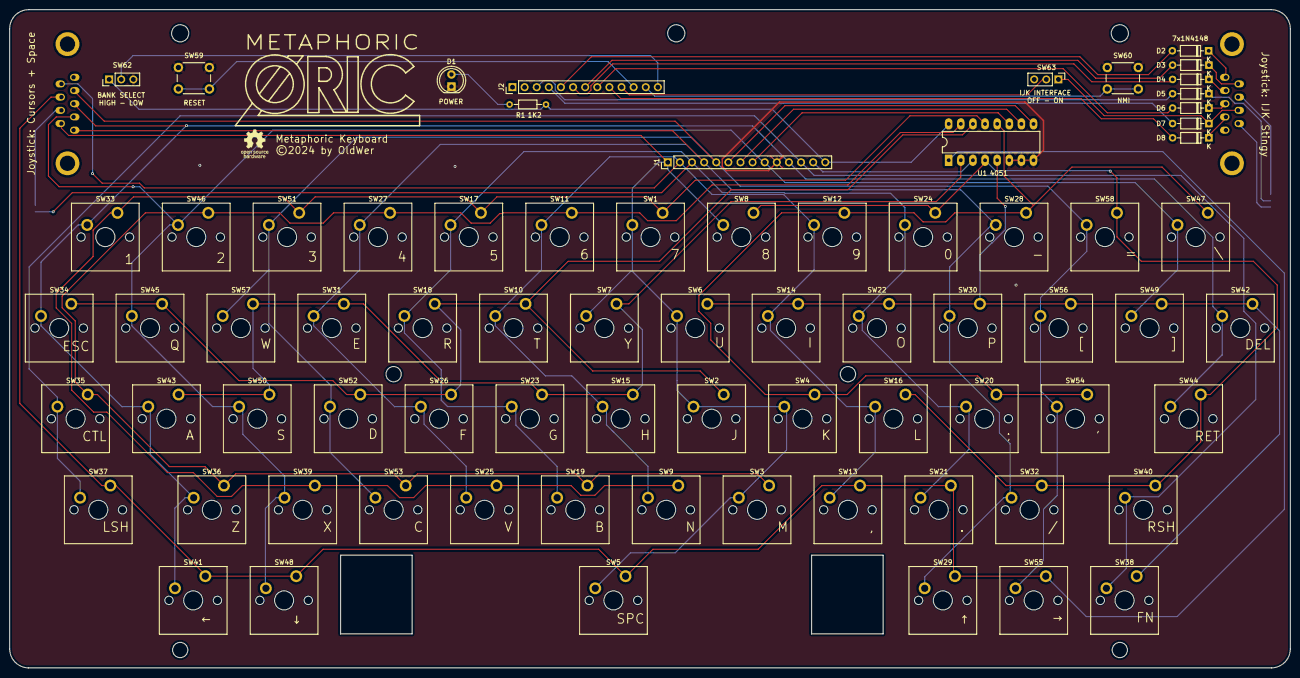
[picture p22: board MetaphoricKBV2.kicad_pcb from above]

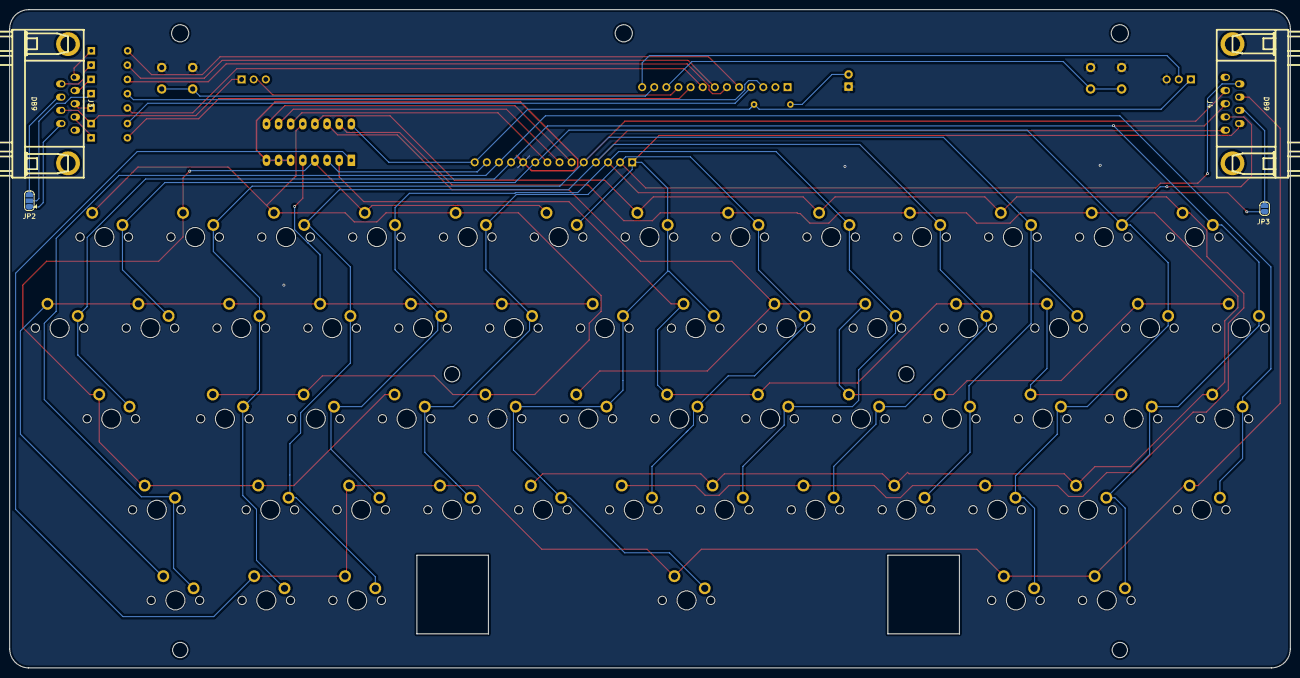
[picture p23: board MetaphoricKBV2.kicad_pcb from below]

Board: 2 copper layers, 268.5 x 138.0 mm, 78 parts (4 on the bottom side), 44 nets.

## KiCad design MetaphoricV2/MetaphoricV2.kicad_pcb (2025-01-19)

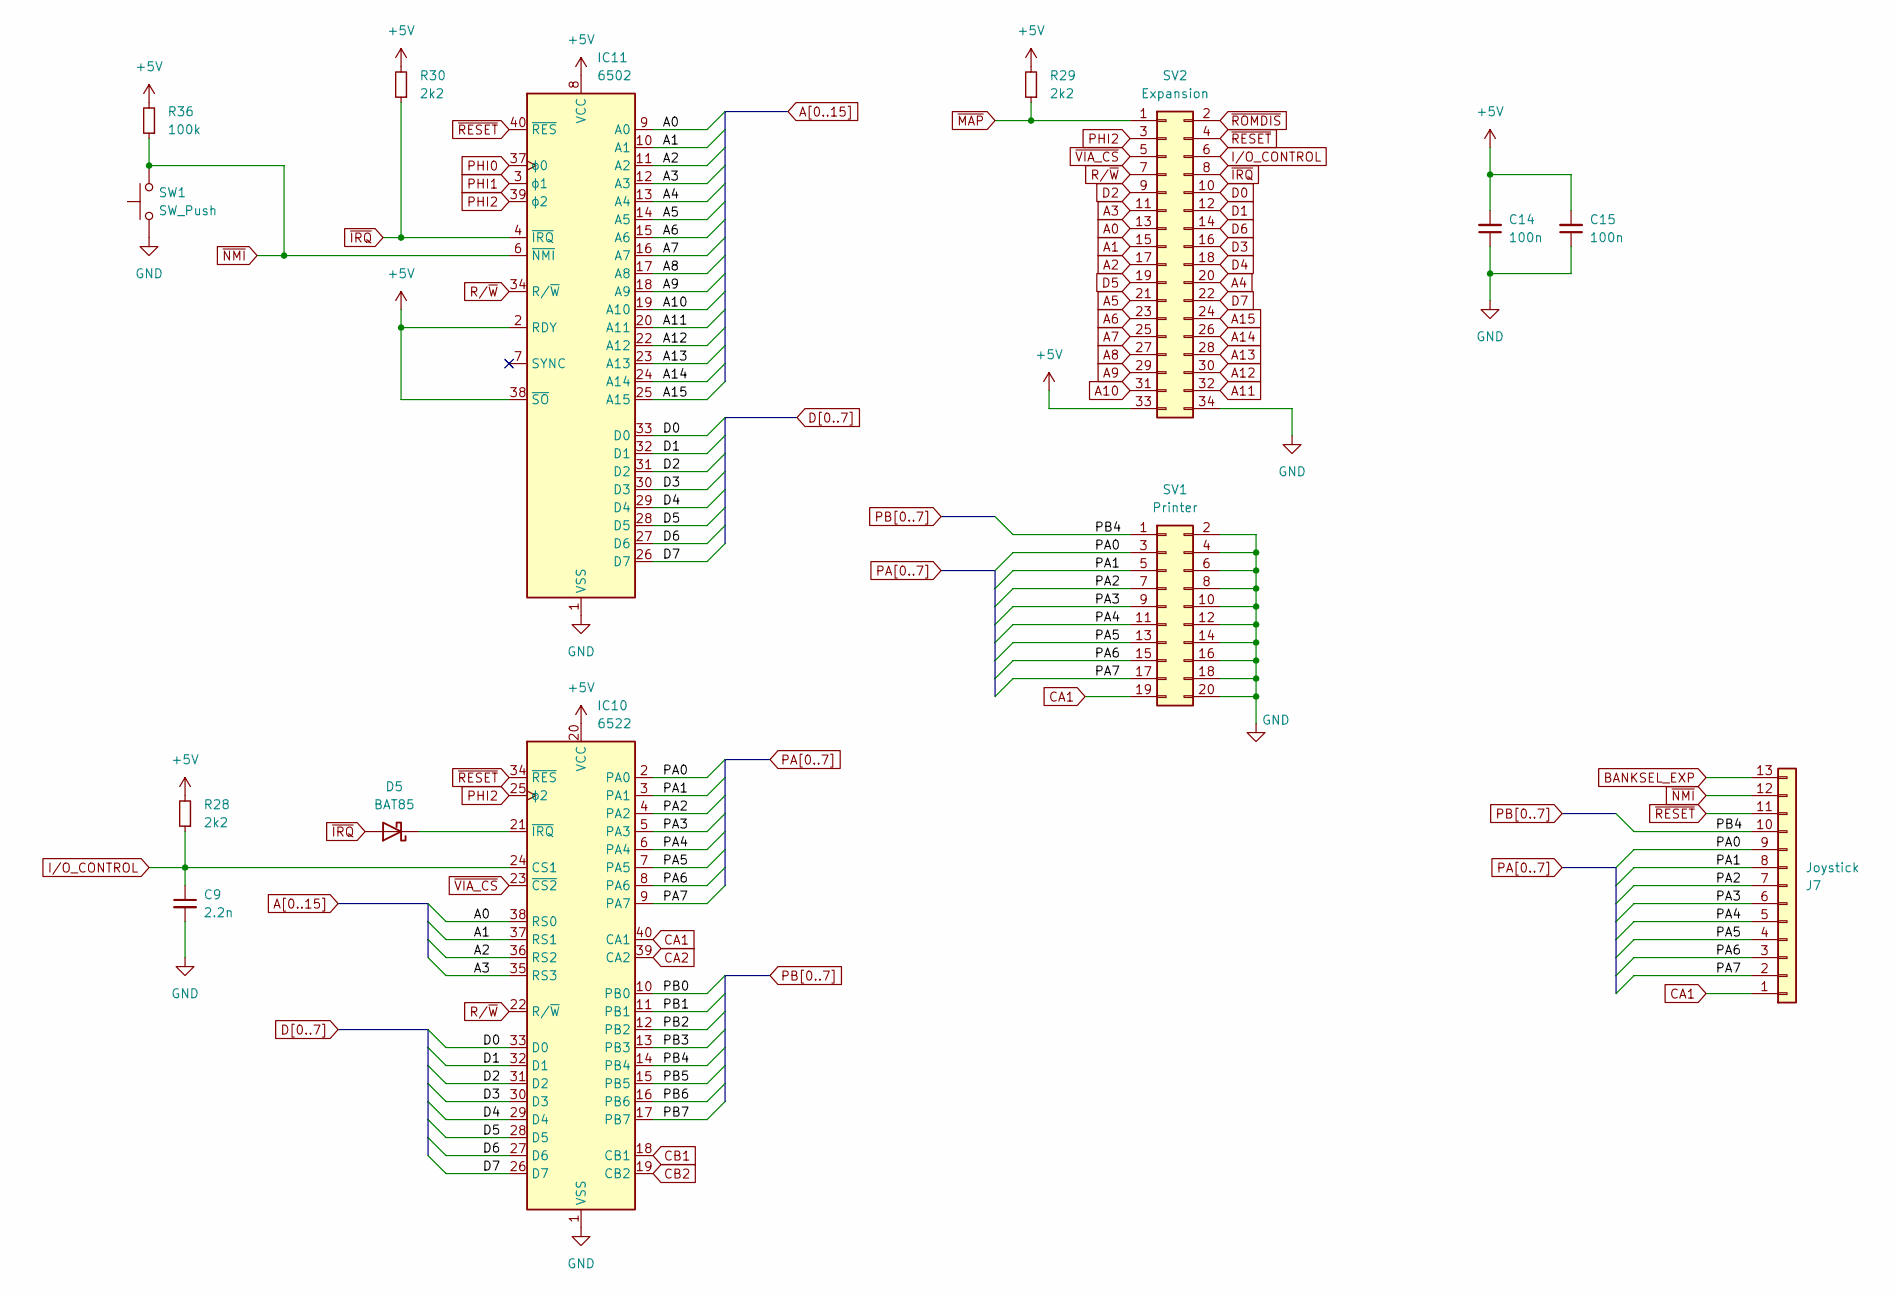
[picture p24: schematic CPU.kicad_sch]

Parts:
C9: 2.2n; C_Disc_D5.0mm_W2.5mm_P5.00mm
C14, C15: 100n; C_Disc_D5.0mm_W2.5mm_P5.00mm
D5: BAT85; D_DO-35_SOD27_P7.62mm_Horizontal
IC10: 6522; DIP-40_W15.24mm_LongPads
IC11: 6502; DIP-40_W15.24mm_LongPads
J7: Joystick; PinHeader_1x13_P2.54mm_Vertical
R28, R29, R30: 2k2; R_Axial_DIN0207_L6.3mm_D2.5mm_P7.62mm_Horizontal
R36: 100k; R_Axial_DIN0207_L6.3mm_D2.5mm_P7.62mm_Horizontal
SV1: Printer; IDC-Header_2x10_P2.54mm_Horizontal
SV2: Expansion; IDC-Header_2x17_P2.54mm_Horizontal
SW1: SW_Push; SW_PUSH_6mm_H4.3mm

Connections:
+5V: C14.2, C15.2, IC10.20 (VCC), IC11.2 (RDY), IC11.8 (VCC), IC11.38 (~SO), R28.2, R29.2, R30.2, R36.2, SV2.33; also elsewhere on the board
A0: IC10.38 (RS0), IC11.9 (A0), SV2.13; also elsewhere on the board
A1: IC10.37 (RS1), IC11.10 (A1), SV2.15; also elsewhere on the board
A2: IC10.36 (RS2), IC11.11 (A2), SV2.17; also elsewhere on the board
A3: IC10.35 (RS3), IC11.12 (A3), SV2.11; also elsewhere on the board
A4: IC11.13 (A4), SV2.20; also elsewhere on the board
A5: IC11.14 (A5), SV2.21; also elsewhere on the board
A6: IC11.15 (A6), SV2.23; also elsewhere on the board
A7: IC11.16 (A7), SV2.25; also elsewhere on the board
A8: IC11.17 (A8), SV2.27; also elsewhere on the board
A9: IC11.18 (A9), SV2.29; also elsewhere on the board
A10: IC11.19 (A10), SV2.31; also elsewhere on the board
A11: IC11.20 (A11), SV2.32; also elsewhere on the board
A12: IC11.22 (A12), SV2.30; also elsewhere on the board
A13: IC11.23 (A13), SV2.28; also elsewhere on the board
A14: IC11.24 (A14), SV2.26; also elsewhere on the board
A15: IC11.25 (A15), SV2.24; also elsewhere on the board
BANKSEL_EXP: J7.13; also elsewhere on the board
CA1: IC10.40 (CA1), J7.1, SV1.19
CA2: IC10.39 (CA2); also elsewhere on the board
CB1: IC10.18 (CB1); also elsewhere on the board
CB2: IC10.19 (CB2); also elsewhere on the board
D0: IC10.33 (D0), IC11.33 (D0), SV2.10; also elsewhere on the board
D1: IC10.32 (D1), IC11.32 (D1), SV2.12; also elsewhere on the board
D2: IC10.31 (D2), IC11.31 (D2), SV2.9; also elsewhere on the board
D3: IC10.30 (D3), IC11.30 (D3), SV2.16; also elsewhere on the board
D4: IC10.29 (D4), IC11.29 (D4), SV2.18; also elsewhere on the board
D5: IC10.28 (D5), IC11.28 (D5), SV2.19; also elsewhere on the board
D6: IC10.27 (D6), IC11.27 (D6), SV2.14; also elsewhere on the board
D7: IC10.26 (D7), IC11.26 (D7), SV2.22; also elsewhere on the board
GND: C9.2, C14.1, C15.1, IC10.1 (VSS), IC11.1 (VSS), IC11.21 (VSS), SV1.2, SV1.4, SV1.6, SV1.8, SV1.10, SV1.12, SV1.14, SV1.16, SV1.18, SV1.20, SV2.34, SW1.1; also elsewhere on the board
I/O_CONTROL: C9.1, IC10.24 (CS1), R28.1, SV2.6
unnamed: D5.1 (K), IC10.21 (~IRQ)
PA0: IC10.2 (PA0), J7.9, SV1.3; also elsewhere on the board
PA1: IC10.3 (PA1), J7.8, SV1.5; also elsewhere on the board
PA2: IC10.4 (PA2), J7.7, SV1.7; also elsewhere on the board
PA3: IC10.5 (PA3), J7.6, SV1.9; also elsewhere on the board
PA4: IC10.6 (PA4), J7.5, SV1.11; also elsewhere on the board
PA5: IC10.7 (PA5), J7.4, SV1.13; also elsewhere on the board
PA6: IC10.8 (PA6), J7.3, SV1.15; also elsewhere on the board
PA7: IC10.9 (PA7), J7.2, SV1.17; also elsewhere on the board
PB0: IC10.10 (PB0); also elsewhere on the board
PB1: IC10.11 (PB1); also elsewhere on the board
PB2: IC10.12 (PB2); also elsewhere on the board
PB3: IC10.13 (PB3); also elsewhere on the board
PB4: IC10.14 (PB4), J7.10, SV1.1
PB5: IC10.15 (PB5); also elsewhere on the board
PB6: IC10.16 (PB6); also elsewhere on the board
PB7: IC10.17 (PB7); also elsewhere on the board
PHI0: IC11.37 (ϕ0); also elsewhere on the board
PHI1: IC11.3 (ϕ1); also elsewhere on the board
PHI2: IC10.25 (ϕ2), IC11.39 (ϕ2), SV2.3; also elsewhere on the board
R/~W: IC10.22 (R/~W), IC11.34 (R/~W), SV2.7; also elsewhere on the board
~IRQ: D5.2 (A), IC11.4 (~IRQ), R30.1, SV2.8
~MAP: R29.1, SV2.1; also elsewhere on the board
~NMI: IC11.6 (~NMI), J7.12, R36.1, SW1.2
~RESET: IC10.34 (~RES), IC11.40 (~RES), J7.11, SV2.4; also elsewhere on the board
~ROMDIS: SV2.2; also elsewhere on the board
~VIA_CS: IC10.23 (~CS2), SV2.5; also elsewhere on the board

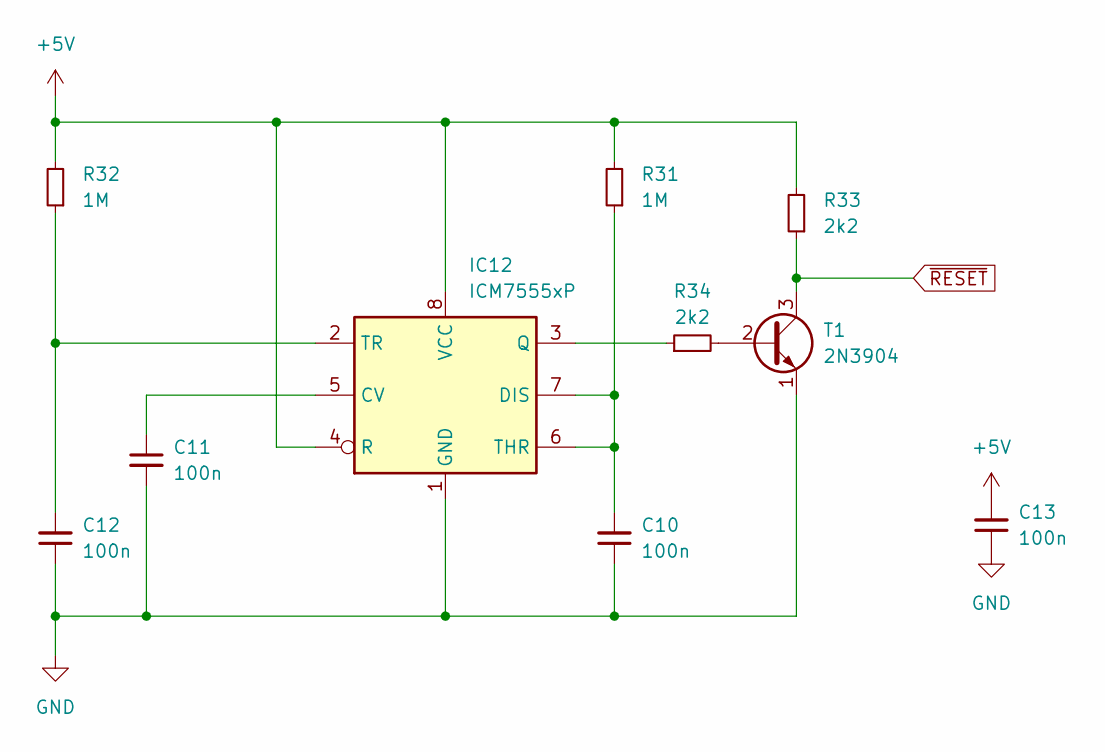
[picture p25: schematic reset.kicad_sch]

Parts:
C10, C11, C12, C13: 100n; C_Disc_D5.0mm_W2.5mm_P5.00mm
IC12: ICM7555xP; DIP-8_W7.62mm
R31, R32: 1M; R_Axial_DIN0207_L6.3mm_D2.5mm_P7.62mm_Horizontal
R33, R34: 2k2; R_Axial_DIN0207_L6.3mm_D2.5mm_P7.62mm_Horizontal
T1: 2N3904; TO-92_Inline

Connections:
+5V: C13.2, IC12.4 (R), IC12.8 (VCC), R31.2, R32.2, R33.2; also elsewhere on the board
GND: C10.1, C11.2, C12.1, C13.1, IC12.1 (GND), T1.1 (E); also elsewhere on the board
unnamed: C11.1, IC12.5 (CV)
unnamed: C10.2, IC12.6 (THR), IC12.7 (DIS), R31.1
unnamed: IC12.3 (Q), R34.1
unnamed: C12.2, IC12.2 (TR), R32.1
unnamed: R34.2, T1.2 (B)
~RESET: R33.1, T1.3 (C); also elsewhere on the board

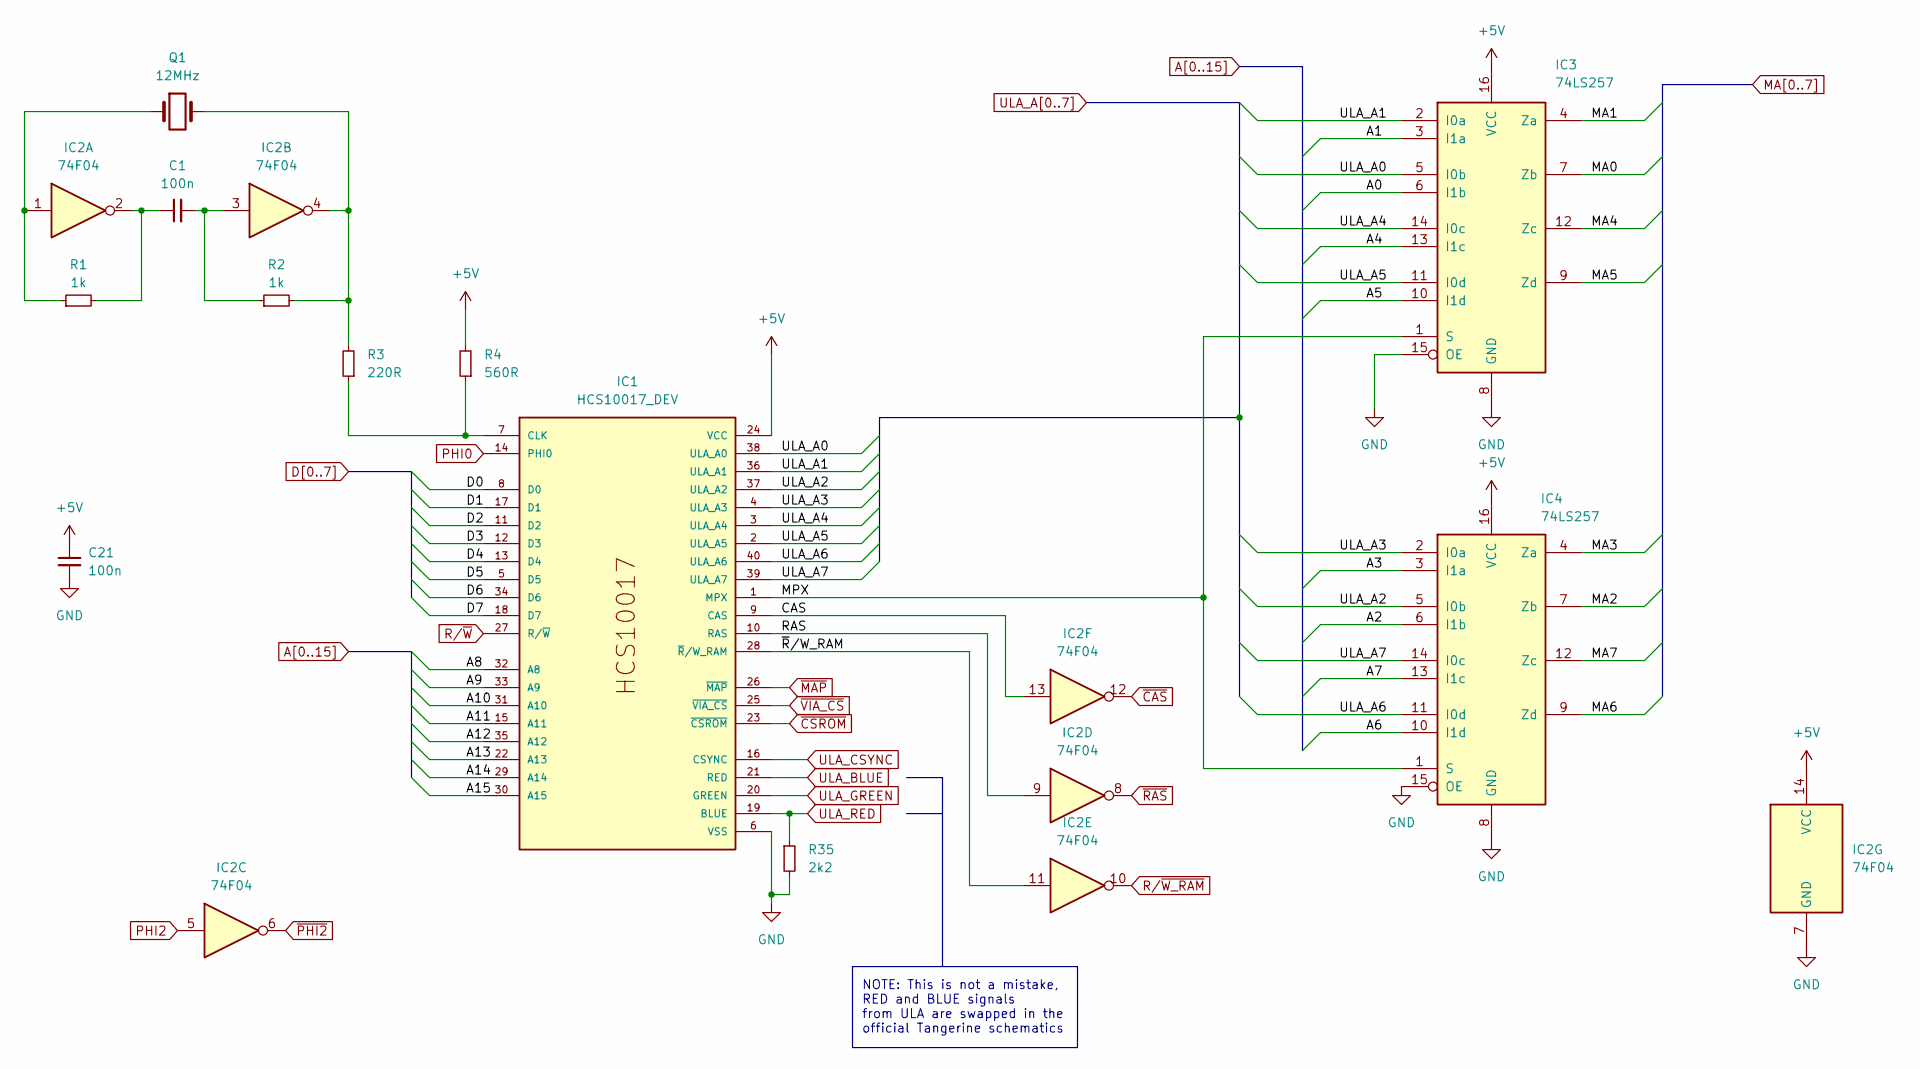
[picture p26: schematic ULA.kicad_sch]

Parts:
C1, C21: 100n; C_Disc_D5.0mm_W2.5mm_P5.00mm
IC1: HCS10017_DEV; DIP-40_W15.24mm_LongPads
IC2: 74F04; DIP-14_W7.62mm_LongPads
IC3, IC4: 74LS257; DIP-16_W7.62mm_LongPads
Q1: 12MHz; Crystal_HC49-4H_Vertical
R1, R2: 1k; R_Axial_DIN0207_L6.3mm_D2.5mm_P7.62mm_Horizontal
R3: 220R; R_Axial_DIN0207_L6.3mm_D2.5mm_P7.62mm_Horizontal
R4: 560R; R_Axial_DIN0207_L6.3mm_D2.5mm_P7.62mm_Horizontal
R35: 2k2; R_Axial_DIN0207_L6.3mm_D2.5mm_P7.62mm_Horizontal

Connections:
+5V: C21.1, IC1.24 (VCC), IC2.14 (VCC), IC3.16 (VCC), IC4.16 (VCC), R4.2; also elsewhere on the board
/ULA/CAS: IC1.9 (CAS), IC2.13
/ULA/MPX: IC1.1 (MPX), IC3.1 (S), IC4.1 (S)
/ULA/RAS: IC1.10 (RAS), IC2.9
/ULA/~R/W_RAM: IC1.28 (~R/W_RAM), IC2.11
A0: IC3.6 (I1b); also elsewhere on the board
A1: IC3.3 (I1a); also elsewhere on the board
A2: IC4.6 (I1b); also elsewhere on the board
A3: IC4.3 (I1a); also elsewhere on the board
A4: IC3.13 (I1c); also elsewhere on the board
A5: IC3.10 (I1d); also elsewhere on the board
A6: IC4.10 (I1d); also elsewhere on the board
A7: IC4.13 (I1c); also elsewhere on the board
A8: IC1.32 (A8); also elsewhere on the board
A9: IC1.33 (A9); also elsewhere on the board
A10: IC1.31 (A10); also elsewhere on the board
A11: IC1.15 (A11); also elsewhere on the board
A12: IC1.35 (A12); also elsewhere on the board
A13: IC1.22 (A13); also elsewhere on the board
A14: IC1.29 (A14); also elsewhere on the board
A15: IC1.30 (A15); also elsewhere on the board
D0: IC1.8 (D0); also elsewhere on the board
D1: IC1.17 (D1); also elsewhere on the board
D2: IC1.11 (D2); also elsewhere on the board
D3: IC1.12 (D3); also elsewhere on the board
D4: IC1.13 (D4); also elsewhere on the board
D5: IC1.5 (D5); also elsewhere on the board
D6: IC1.34 (D6); also elsewhere on the board
D7: IC1.18 (D7); also elsewhere on the board
GND: C21.2, IC1.6 (VSS), IC2.7 (GND), IC3.8 (GND), IC3.15 (OE), IC4.8 (GND), IC4.15 (OE), R35.2; also elsewhere on the board
MA0: IC3.7 (Zb); also elsewhere on the board
MA1: IC3.4 (Za); also elsewhere on the board
MA2: IC4.7 (Zb); also elsewhere on the board
MA3: IC4.4 (Za); also elsewhere on the board
MA4: IC3.12 (Zc); also elsewhere on the board
MA5: IC3.9 (Zd); also elsewhere on the board
MA6: IC4.9 (Zd); also elsewhere on the board
MA7: IC4.12 (Zc); also elsewhere on the board
unnamed: C1.1, IC2.2, R1.2
unnamed: C1.2, IC2.3, R2.1
unnamed: IC1.7 (CLK), R3.1, R4.1
unnamed: IC2.1, Q1.1, R1.1
unnamed: IC2.4, Q1.2, R2.2, R3.2
PHI0: IC1.14 (PHI0); also elsewhere on the board
PHI2: IC2.5; also elsewhere on the board
R/~W_RAM: IC2.10; also elsewhere on the board
R/~W: IC1.27 (R/~W); also elsewhere on the board
ULA_A0: IC1.38 (ULA_A0), IC3.5 (I0b)
ULA_A1: IC1.36 (ULA_A1), IC3.2 (I0a)
ULA_A2: IC1.37 (ULA_A2), IC4.5 (I0b)
ULA_A3: IC1.4 (ULA_A3), IC4.2 (I0a)
ULA_A4: IC1.3 (ULA_A4), IC3.14 (I0c)
ULA_A5: IC1.2 (ULA_A5), IC3.11 (I0d)
ULA_A6: IC1.40 (ULA_A6), IC4.11 (I0d)
ULA_A7: IC1.39 (ULA_A7), IC4.14 (I0c)
ULA_BLUE: IC1.21 (RED); also elsewhere on the board
ULA_CSYNC: IC1.16 (CSYNC); also elsewhere on the board
ULA_GREEN: IC1.20 (GREEN); also elsewhere on the board
ULA_RED: IC1.19 (BLUE), R35.1; also elsewhere on the board
~CAS: IC2.12; also elsewhere on the board
~CSROM: IC1.23 (~CSROM); also elsewhere on the board
~MAP: IC1.26 (~MAP); also elsewhere on the board
~PHI2: IC2.6; also elsewhere on the board
~RAS: IC2.8; also elsewhere on the board
~VIA_CS: IC1.25 (~VIA_CS); also elsewhere on the board

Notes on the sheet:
NOTE: This is not a mistake, RED and BLUE signals from ULA are swapped in the official Tangerine schematics

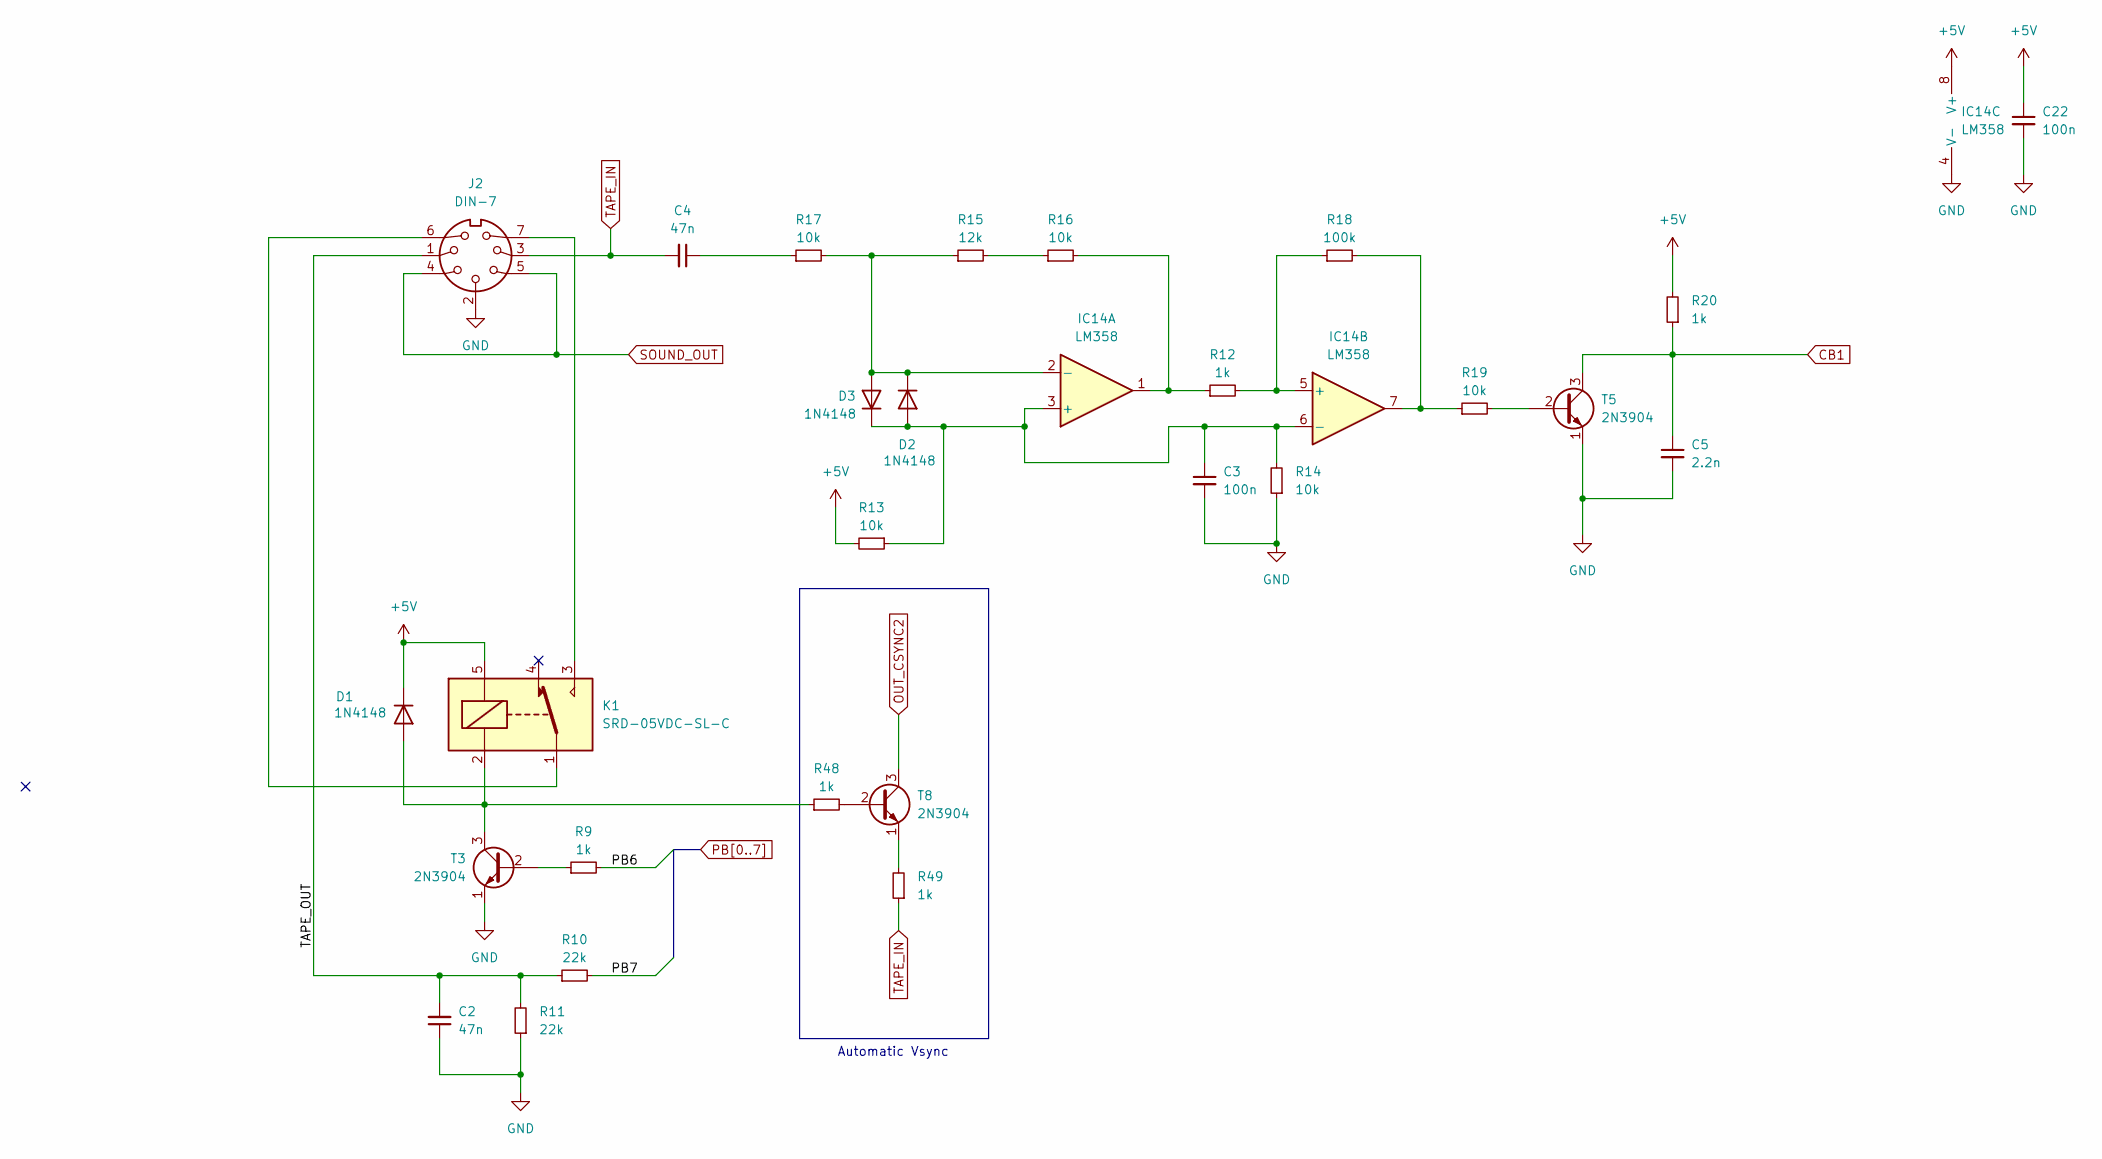
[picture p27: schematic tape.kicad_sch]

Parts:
C2, C4: 47n; C_Disc_D5.0mm_W2.5mm_P5.00mm
C3, C22: 100n; C_Disc_D5.0mm_W2.5mm_P5.00mm
C5: 2.2n; C_Disc_D5.0mm_W2.5mm_P5.00mm
D1, D2, D3: 1N4148; D_DO-35_SOD27_P7.62mm_Horizontal
IC14: LM358; DIP-8_W7.62mm_LongPads
J2: DIN-7; AV_CON_DIN7
K1: SRD-05VDC-SL-C; Relay_SPDT_SANYOU_SRD_Series_Form_C
R9, R12, R20, R48, R49: 1k; R_Axial_DIN0207_L6.3mm_D2.5mm_P7.62mm_Horizontal
R10, R11: 22k; R_Axial_DIN0207_L6.3mm_D2.5mm_P7.62mm_Horizontal
R13, R14, R16, R17, R19: 10k; R_Axial_DIN0207_L6.3mm_D2.5mm_P7.62mm_Horizontal
R15: 12k; R_Axial_DIN0207_L6.3mm_D2.5mm_P7.62mm_Horizontal
R18: 100k; R_Axial_DIN0207_L6.3mm_D2.5mm_P7.62mm_Horizontal
T3, T5, T8: 2N3904; TO-92_Inline

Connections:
+5V: C22.1, D1.1 (K), IC14.8 (V+), K1.5, R13.2, R20.2; also elsewhere on the board
/Tape/TAPE_OUT: C2.2, J2.1, R10.1, R11.2
CB1: C5.1, R20.1, T5.3 (C); also elsewhere on the board
GND: C2.1, C3.2, C5.2, C22.2, IC14.4 (V-), J2.2, R11.1, R14.1, T3.1 (E), T5.1 (E); also elsewhere on the board
unnamed: C4.1, R17.1
unnamed: D1.2 (A), K1.2, R48.1, T3.3 (C)
unnamed: C3.1, D2.2 (A), D3.1 (K), IC14.3 (+), IC14.6 (-), R13.1, R14.2
unnamed: D2.1 (K), D3.2 (A), IC14.2 (-), R15.1, R17.2
unnamed: IC14.1, R12.1, R16.2
unnamed: IC14.7, R18.2, R19.1
unnamed: IC14.5 (+), R12.2, R18.1
unnamed: J2.6, K1.1
unnamed: J2.7, K1.3
unnamed: R15.2, R16.1
unnamed: R9.1, T3.2 (B)
unnamed: R19.2, T5.2 (B)
unnamed: R48.2, T8.2 (B)
unnamed: R49.2, T8.1 (E)
OUT_CSYNC2: T8.3 (C); also elsewhere on the board
PB6: R9.2; also elsewhere on the board
PB7: R10.2; also elsewhere on the board
SOUND_OUT: J2.4, J2.5; also elsewhere on the board
TAPE_IN: C4.2, J2.3, R49.1

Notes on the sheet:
Automatic Vsync

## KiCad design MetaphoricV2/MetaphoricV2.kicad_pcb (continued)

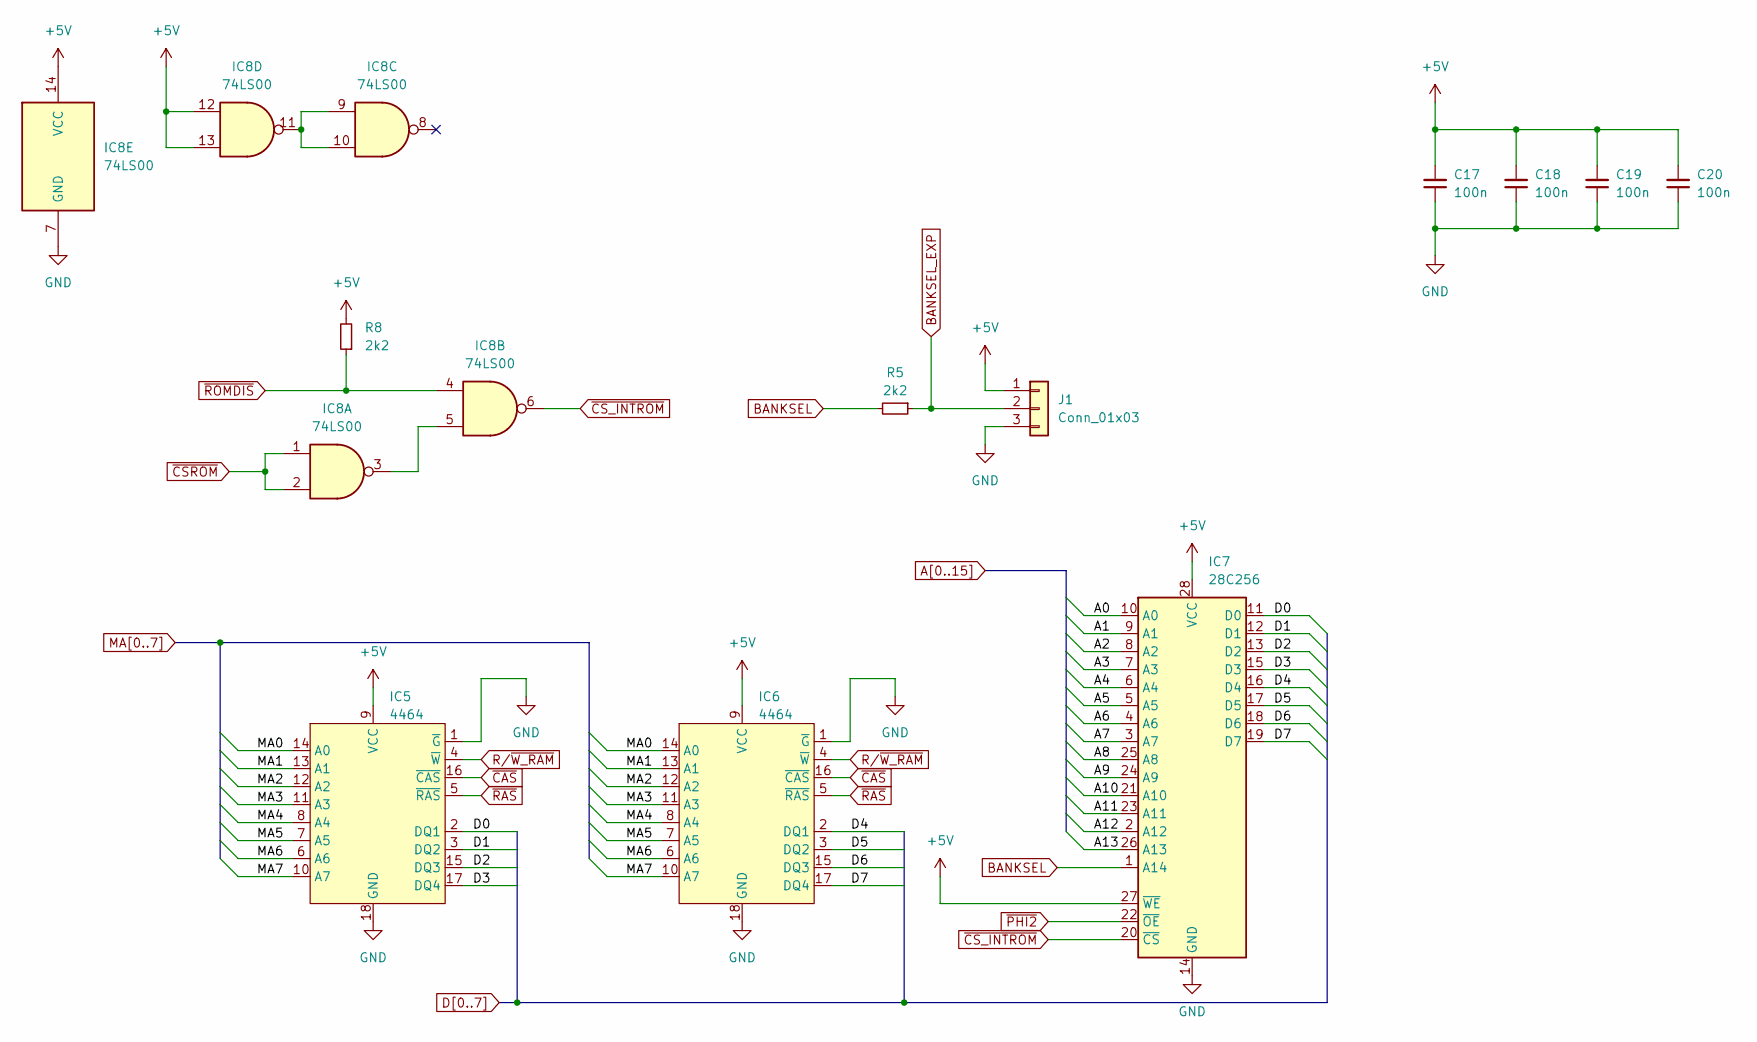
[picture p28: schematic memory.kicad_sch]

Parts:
C17, C18, C19, C20: 100n; C_Disc_D5.0mm_W2.5mm_P5.00mm
IC5, IC6: 4464; DIP-18_W7.62mm_LongPads
IC7: 28C256; DIP-28_W15.24mm_LongPads
IC8: 74LS00; DIP-14_W7.62mm_LongPads
J1: Conn_01x03; PinHeader_1x03_P2.54mm_Vertical
R5, R8: 2k2; R_Axial_DIN0207_L6.3mm_D2.5mm_P7.62mm_Horizontal

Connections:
+5V: C17.2, C18.2, C19.2, C20.2, IC5.9 (VCC), IC6.9 (VCC), IC7.27 (~WE), IC7.28 (VCC), IC8.12, IC8.13, IC8.14 (VCC), J1.1, R8.2; also elsewhere on the board
A0: IC7.10 (A0); also elsewhere on the board
A1: IC7.9 (A1); also elsewhere on the board
A2: IC7.8 (A2); also elsewhere on the board
A3: IC7.7 (A3); also elsewhere on the board
A4: IC7.6 (A4); also elsewhere on the board
A5: IC7.5 (A5); also elsewhere on the board
A6: IC7.4 (A6); also elsewhere on the board
A7: IC7.3 (A7); also elsewhere on the board
A8: IC7.25 (A8); also elsewhere on the board
A9: IC7.24 (A9); also elsewhere on the board
A10: IC7.21 (A10); also elsewhere on the board
A11: IC7.23 (A11); also elsewhere on the board
A12: IC7.2 (A12); also elsewhere on the board
A13: IC7.26 (A13); also elsewhere on the board
BANKSEL: IC7.1 (A14), R5.2
BANKSEL_EXP: J1.2, R5.1; also elsewhere on the board
D0: IC5.2 (DQ1), IC7.11 (D0); also elsewhere on the board
D1: IC5.3 (DQ2), IC7.12 (D1); also elsewhere on the board
D2: IC5.15 (DQ3), IC7.13 (D2); also elsewhere on the board
D3: IC5.17 (DQ4), IC7.15 (D3); also elsewhere on the board
D4: IC6.2 (DQ1), IC7.16 (D4); also elsewhere on the board
D5: IC6.3 (DQ2), IC7.17 (D5); also elsewhere on the board
D6: IC6.15 (DQ3), IC7.18 (D6); also elsewhere on the board
D7: IC6.17 (DQ4), IC7.19 (D7); also elsewhere on the board
GND: C17.1, C18.1, C19.1, C20.1, IC5.1 (~G), IC5.18 (GND), IC6.1 (~G), IC6.18 (GND), IC7.14 (GND), IC8.7 (GND), J1.3; also elsewhere on the board
MA0: IC5.14 (A0), IC6.14 (A0); also elsewhere on the board
MA1: IC5.13 (A1), IC6.13 (A1); also elsewhere on the board
MA2: IC5.12 (A2), IC6.12 (A2); also elsewhere on the board
MA3: IC5.11 (A3), IC6.11 (A3); also elsewhere on the board
MA4: IC5.8 (A4), IC6.8 (A4); also elsewhere on the board
MA5: IC5.7 (A5), IC6.7 (A5); also elsewhere on the board
MA6: IC5.6 (A6), IC6.6 (A6); also elsewhere on the board
MA7: IC5.10 (A7), IC6.10 (A7); also elsewhere on the board
unnamed: IC8.3, IC8.5
unnamed: IC8.9, IC8.10, IC8.11
R/~W_RAM: IC5.4 (~W), IC6.4 (~W); also elsewhere on the board
~CAS: IC5.16 (~CAS), IC6.16 (~CAS); also elsewhere on the board
~CSROM: IC8.1, IC8.2; also elsewhere on the board
~CS_INTROM: IC7.20 (~CS), IC8.6
~PHI2: IC7.22 (~OE); also elsewhere on the board
~RAS: IC5.5 (~RAS), IC6.5 (~RAS); also elsewhere on the board
~ROMDIS: IC8.4, R8.1; also elsewhere on the board

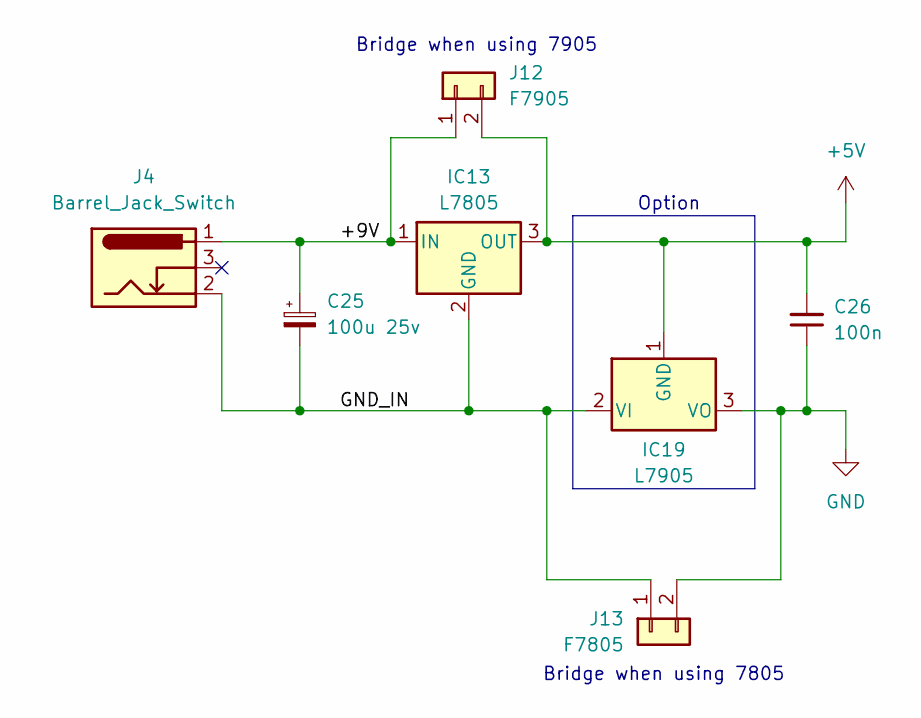
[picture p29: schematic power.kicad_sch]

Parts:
C25: 100u 25v; CP_Radial_D8.0mm_P3.50mm
C26: 100n; C_Disc_D5.0mm_W2.5mm_P5.00mm
IC13: L7805; TO-220-3_Vertical
IC19: L7905; TO-220-3_Vertical
J4: Barrel_Jack_Switch; BarrelJack_Horizontal
J12: F7905; PinHeader_1x02_P2.54mm_Vertical
J13: F7805; PinHeader_1x02_P2.54mm_Vertical

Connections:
+5V: C26.2, IC13.3 (OUT), IC19.1 (GND), J12.2; also elsewhere on the board
/Power/+9V: C25.1, IC13.1 (IN), J4.1, J12.1
/Power/GND_IN: C25.2, IC13.2 (GND), IC19.2 (VI), J4.2, J13.1
GND: C26.1, IC19.3 (VO), J13.2; also elsewhere on the board

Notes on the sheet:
Bridge when using 7805
Option
Bridge when using 7905

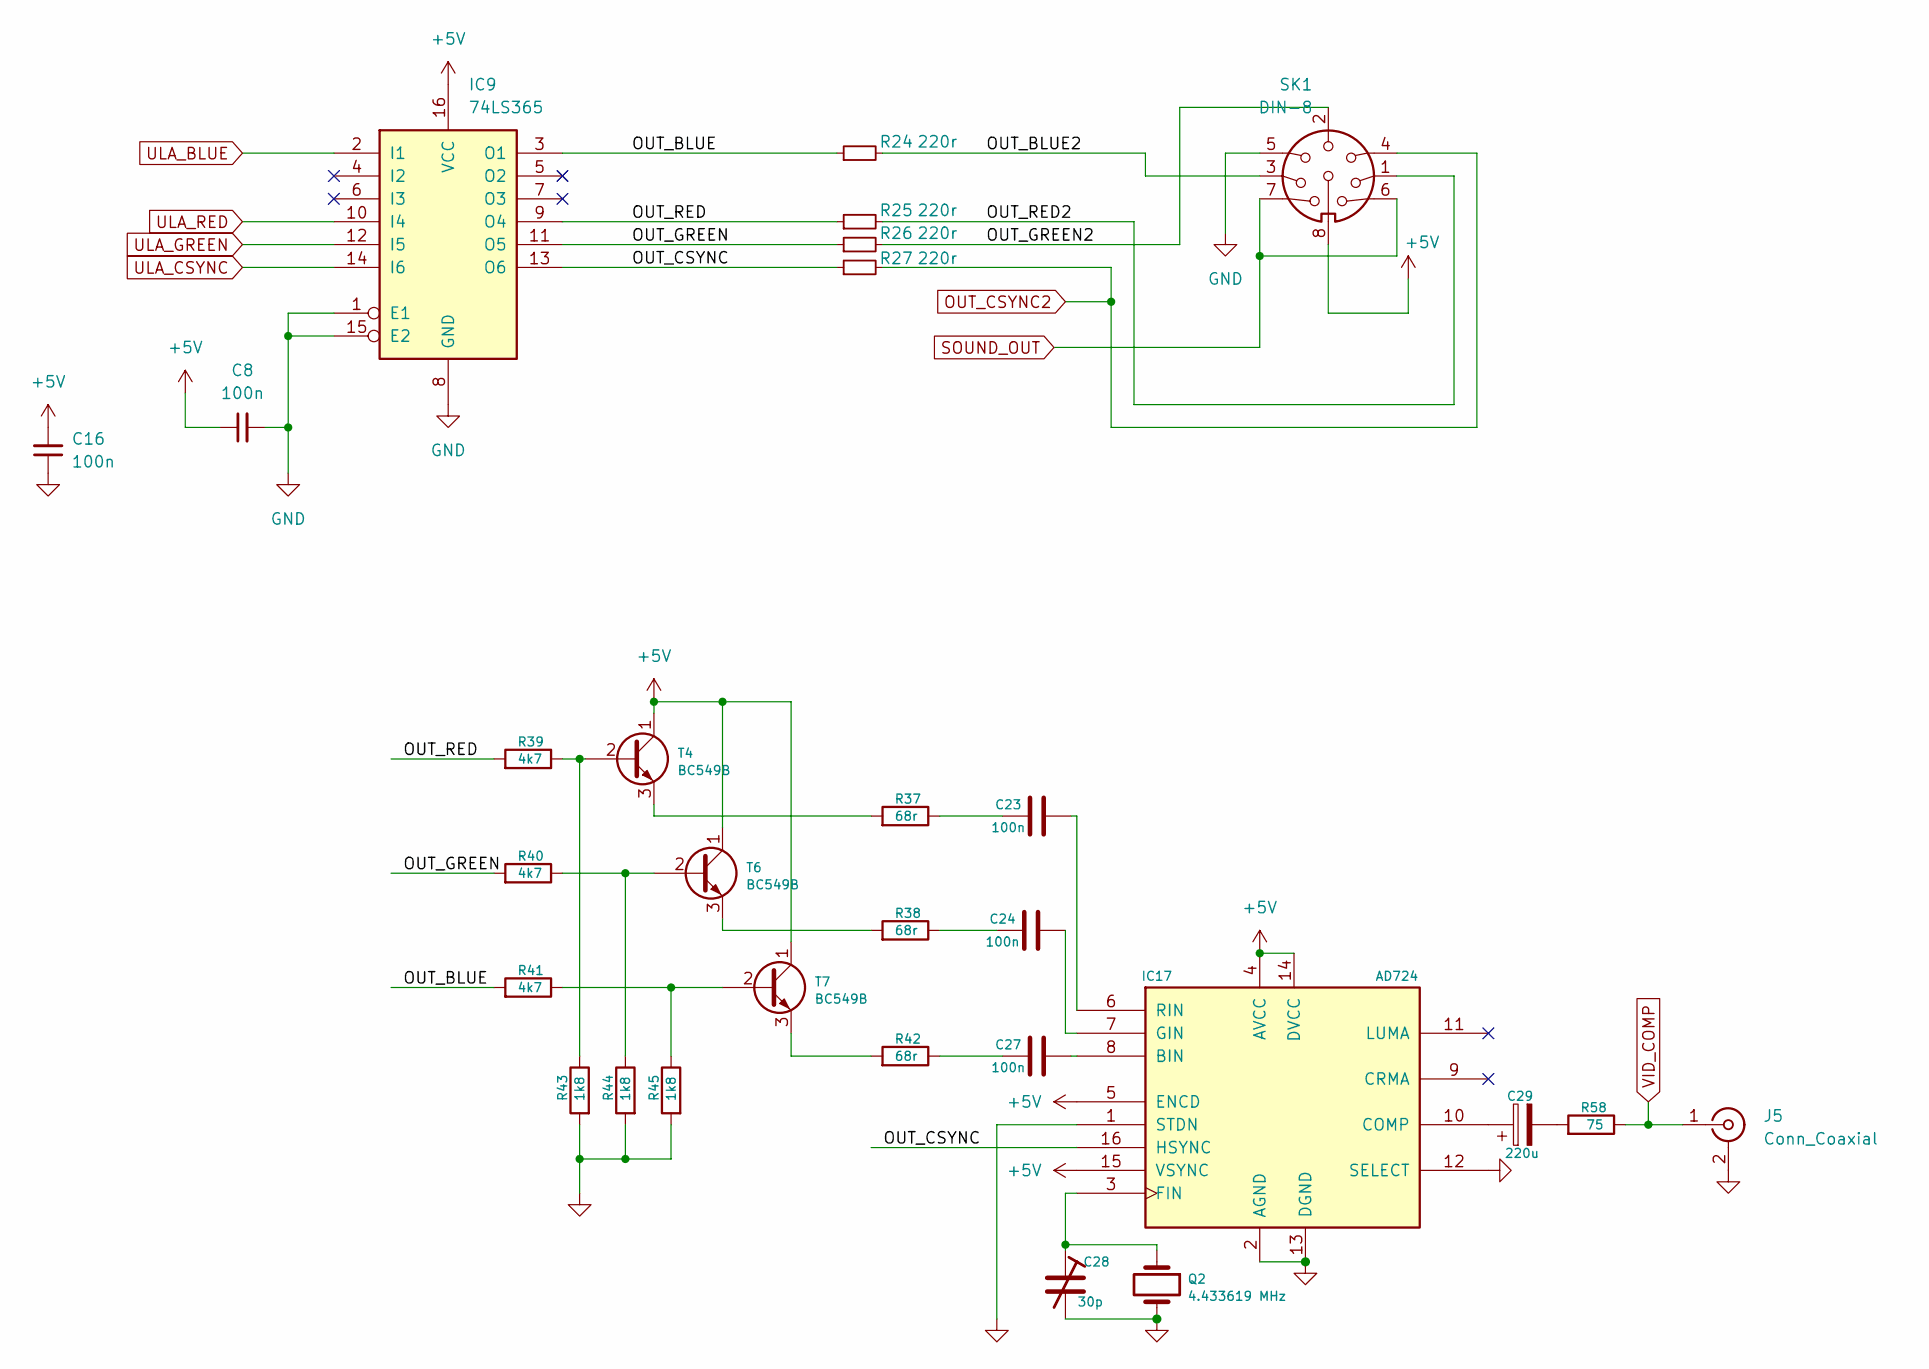
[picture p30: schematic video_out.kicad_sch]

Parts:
C8, C16, C23, C24, C27: 100n; C_Disc_D5.0mm_W2.5mm_P5.00mm
C28: 30p; C_Trim_D6.3mm_P5.50mm
C29: 220u; CP_Radial_D5.0mm_P2.50mm
IC9: 74LS365; DIP-16_W7.62mm_LongPads
IC17: AD724; SOIC-16W_7.5x10.3mm_P1.27mm
J5: Conn_Coaxial; Composite_RCA
Q2: 4.433619 MHz; Crystal_HC49-U_Vertical
R24, R25, R26, R27: 220r; R_Axial_DIN0207_L6.3mm_D2.5mm_P7.62mm_Horizontal
R37, R38, R42: 68r; R_Axial_DIN0207_L6.3mm_D2.5mm_P7.62mm_Horizontal
R39, R40, R41: 4k7; R_Axial_DIN0207_L6.3mm_D2.5mm_P7.62mm_Horizontal
R43, R44, R45: 1k8; R_Axial_DIN0207_L6.3mm_D2.5mm_P7.62mm_Horizontal
R58: 75; R_Axial_DIN0207_L6.3mm_D2.5mm_P7.62mm_Horizontal
SK1: DIN-8; AV_CON_DIN8
T4, T6, T7: BC549B; TO-92

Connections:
+5V: C8.1, C16.2, IC9.16 (VCC), IC17.4 (AVCC), IC17.5 (ENCD), IC17.14 (DVCC), IC17.15 (VSYNC), SK1.8, T4.1 (C), T6.1 (C), T7.1 (C); also elsewhere on the board
/Video Out/OUT_BLUE: IC9.3 (O1), R24.1, R41.2
/Video Out/OUT_BLUE2: R24.2, SK1.3
/Video Out/OUT_CSYNC: IC9.13 (O6), IC17.16 (HSYNC), R27.1
/Video Out/OUT_GREEN: IC9.11 (O5), R26.1, R40.2
/Video Out/OUT_GREEN2: R26.2, SK1.2
/Video Out/OUT_RED: IC9.9 (O4), R25.1, R39.2
/Video Out/OUT_RED2: R25.2, SK1.1
GND: C8.2, C16.1, C28.2, IC9.1 (E1), IC9.8 (GND), IC9.15 (E2), IC17.1 (STDN), IC17.2 (AGND), IC17.12 (SELECT), IC17.13 (DGND), J5.2 (Ext), Q2.2, R43.2, R44.2, R45.2, SK1.5; also elsewhere on the board
unnamed: C23.1, R37.1
unnamed: C24.1, R38.1
unnamed: C27.1, R42.1
unnamed: C29.2, R58.2
unnamed: C27.2, IC17.8 (BIN)
unnamed: C29.1, IC17.10 (COMP)
unnamed: C28.1, IC17.3 (FIN), Q2.1
unnamed: C24.2, IC17.7 (GIN)
unnamed: C23.2, IC17.6 (RIN)
unnamed: R39.1, R43.1, T4.2 (B)
unnamed: R37.2, T4.3 (E)
unnamed: R40.1, R44.1, T6.2 (B)
unnamed: R38.2, T6.3 (E)
unnamed: R41.1, R45.1, T7.2 (B)
unnamed: R42.2, T7.3 (E)
OUT_CSYNC2: R27.2, SK1.4; also elsewhere on the board
SOUND_OUT: SK1.6, SK1.7; also elsewhere on the board
ULA_BLUE: IC9.2 (I1); also elsewhere on the board
ULA_CSYNC: IC9.14 (I6); also elsewhere on the board
ULA_GREEN: IC9.12 (I5); also elsewhere on the board
ULA_RED: IC9.10 (I4); also elsewhere on the board
VID_COMP: J5.1 (In), R58.1; also elsewhere on the board

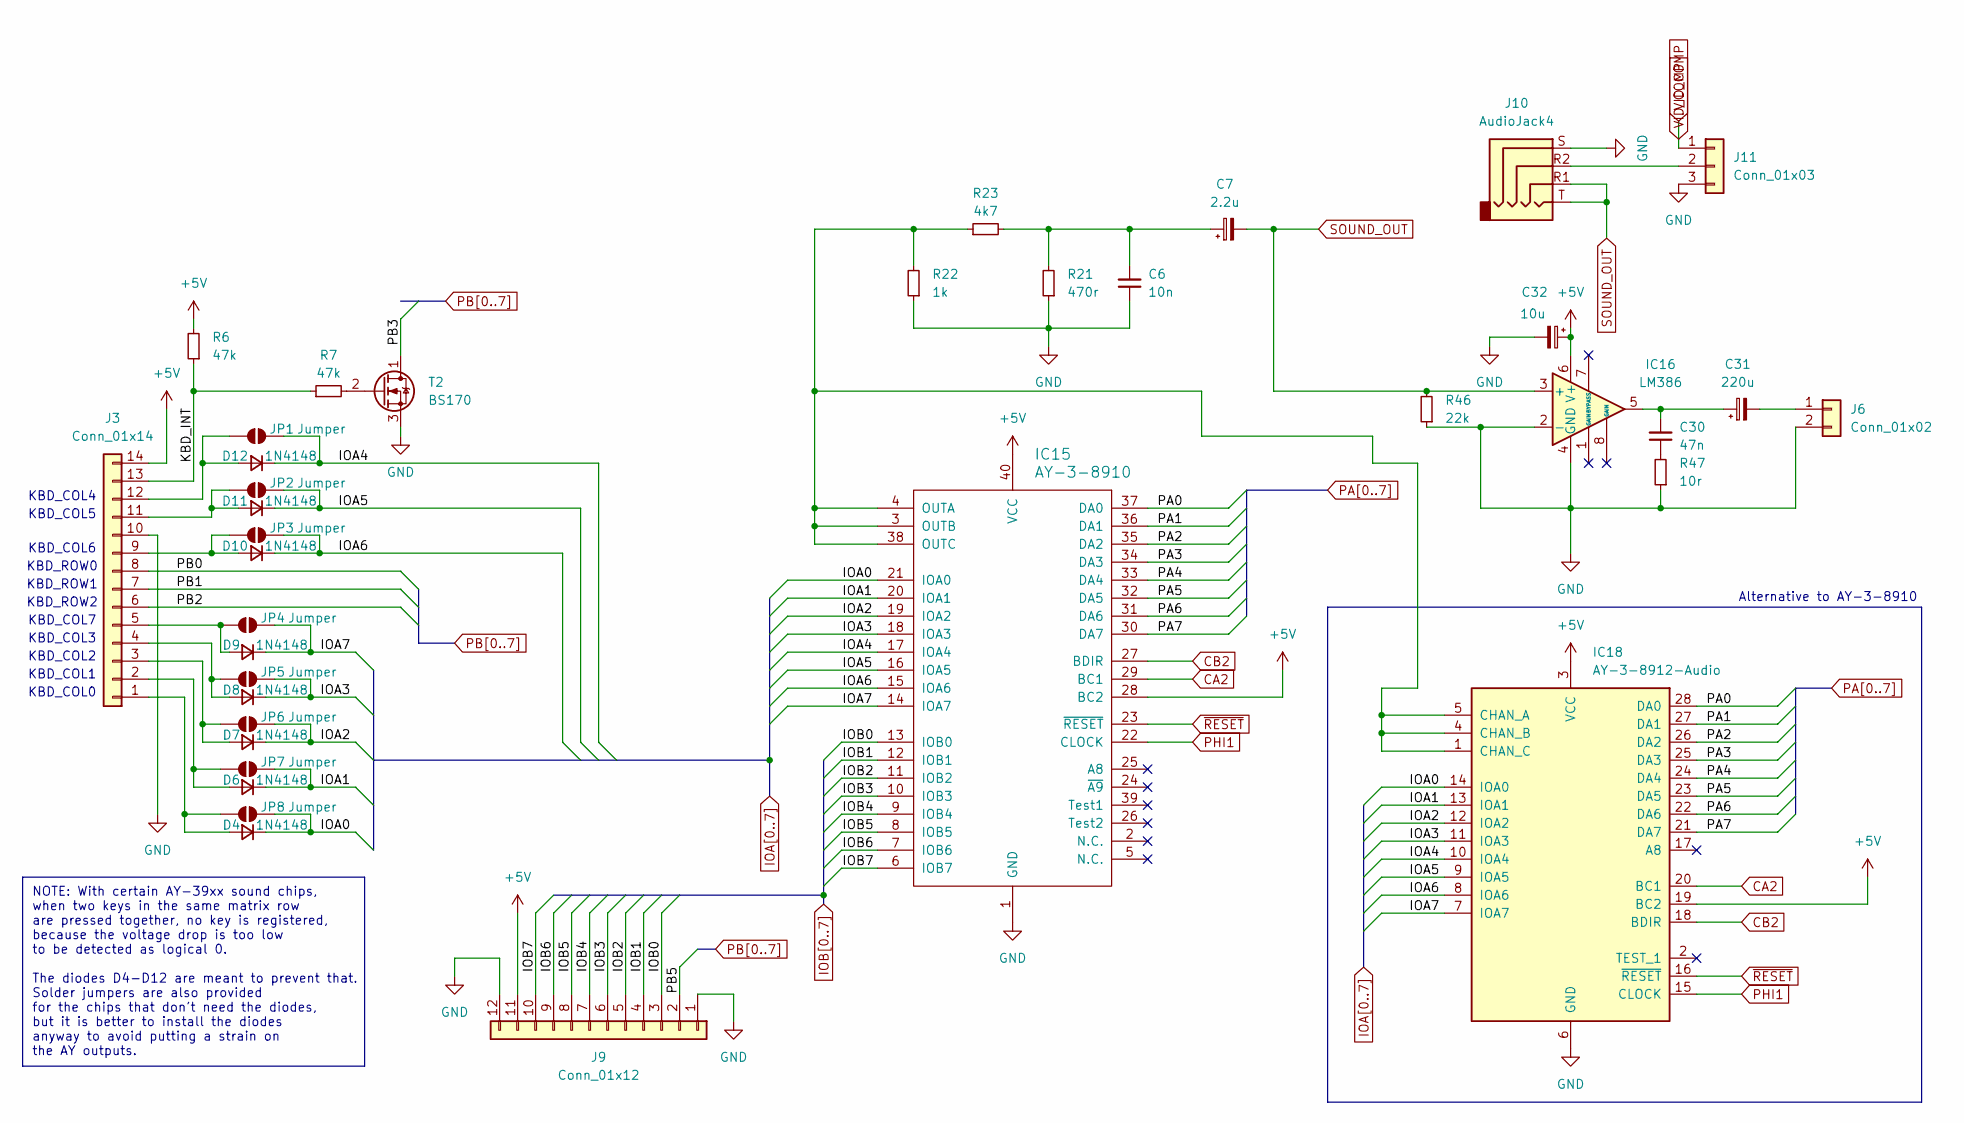
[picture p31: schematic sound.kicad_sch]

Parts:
C6: 10n; C_Disc_D5.0mm_W2.5mm_P5.00mm
C7: 2.2u; CP_Radial_D5.0mm_P2.50mm
C30: 47n; C_Disc_D5.0mm_W2.5mm_P5.00mm
C31: 220u; CP_Radial_D5.0mm_P2.50mm
C32: 10u; CP_Radial_D5.0mm_P2.50mm
D4, D6, D7, D8, D9, D10, D11, D12: 1N4148; D_DO-35_SOD27_P7.62mm_Horizontal
IC15: AY-3-8910; DIP-40_W15.24mm_LongPads
IC16: LM386; DIP-8_W7.62mm
IC18: AY-3-8912-Audio; DIP-28_W15.24mm_LongPads
J3: Conn_01x14; PinHeader_1x14_P2.54mm_Vertical
J6: Conn_01x02; PinHeader_1x02_P2.54mm_Vertical
J9: Conn_01x12; PinHeader_1x12_P2.54mm_Vertical
J10: AudioJack4; PJ-322
J11: Conn_01x03; PinHeader_1x03_P2.54mm_Vertical
JP1, JP2, JP3, JP4, JP5, JP6, JP7, JP8: Jumper; SolderJumper-2_P1.3mm_Open_RoundedPad1.0x1.5mm
R6, R7: 47k; R_Axial_DIN0207_L6.3mm_D2.5mm_P7.62mm_Horizontal
R21: 470r; R_Axial_DIN0207_L6.3mm_D2.5mm_P7.62mm_Horizontal
R22: 1k; R_Axial_DIN0207_L6.3mm_D2.5mm_P7.62mm_Horizontal
R23: 4k7; R_Axial_DIN0207_L6.3mm_D2.5mm_P7.62mm_Horizontal
R46: 22k; R_Axial_DIN0207_L6.3mm_D2.5mm_P7.62mm_Horizontal
R47: 10r; R_Axial_DIN0207_L6.3mm_D2.5mm_P7.62mm_Horizontal
T2: BS170; TO-92_Inline

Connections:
+5V: C32.1, IC15.28 (BC2), IC15.40 (VCC), IC16.6 (V+), IC18.3 (VCC), IC18.19 (BC2), J3.14, J9.11, R6.2; also elsewhere on the board
/Sound/KBD_INT: J3.13, R6.1, R7.1
CA2: IC15.29 (BC1), IC18.20 (BC1); also elsewhere on the board
CB2: IC15.27 (BDIR), IC18.18 (BDIR); also elsewhere on the board
GND: C6.1, C32.2, IC15.1 (GND), IC16.2 (-), IC16.4 (GND), IC18.6 (GND), J3.10, J6.2, J9.1, J9.12, J10.S, J11.3, R21.1, R22.1, R46.1, R47.1, T2.3 (S); also elsewhere on the board
IOA0: D4.1 (K), IC15.21 (IOA0), IC18.14 (IOA0), JP8.2 (B)
IOA1: D6.1 (K), IC15.20 (IOA1), IC18.13 (IOA1), JP7.2 (B)
IOA2: D7.1 (K), IC15.19 (IOA2), IC18.12 (IOA2), JP6.2 (B)
IOA3: D8.1 (K), IC15.18 (IOA3), IC18.11 (IOA3), JP5.2 (B)
IOA4: D12.1 (K), IC15.17 (IOA4), IC18.10 (IOA4), JP1.2 (B)
IOA5: D11.1 (K), IC15.16 (IOA5), IC18.9 (IOA5), JP2.2 (B)
IOA6: D10.1 (K), IC15.15 (IOA6), IC18.8 (IOA6), JP3.2 (B)
IOA7: D9.1 (K), IC15.14 (IOA7), IC18.7 (IOA7), JP4.2 (B)
IOB0: IC15.13 (IOB0), J9.3
IOB1: IC15.12 (IOB1), J9.4
IOB2: IC15.11 (IOB2), J9.5
IOB3: IC15.10 (IOB3), J9.6
IOB4: IC15.9 (IOB4), J9.7
IOB5: IC15.8 (IOB5), J9.8
IOB6: IC15.7 (IOB6), J9.9
IOB7: IC15.6 (IOB7), J9.10
unnamed: C6.2, C7.1, R21.2, R23.2
unnamed: C30.1, R47.2
unnamed: C30.2, C31.1, IC16.5
unnamed: D4.2 (A), J3.1, JP8.1 (A)
unnamed: D6.2 (A), J3.2, JP7.1 (A)
unnamed: D7.2 (A), J3.3, JP6.1 (A)
unnamed: D8.2 (A), J3.4, JP5.1 (A)
unnamed: D9.2 (A), J3.5, JP4.1 (A)
unnamed: D10.2 (A), J3.9, JP3.1 (A)
unnamed: D11.2 (A), J3.11, JP2.1 (A)
unnamed: D12.2 (A), J3.12, JP1.1 (A)
unnamed: IC15.3 (OUTB), IC15.4 (OUTA), IC15.38 (OUTC), IC18.1 (CHAN_C), IC18.4 (CHAN_B), IC18.5 (CHAN_A), R22.2, R23.1
unnamed: C31.2, J6.1
unnamed: J10.R2, J11.2
unnamed: R7.2, T2.2 (G)
PA0: IC15.37 (DA0), IC18.28 (DA0); also elsewhere on the board
PA1: IC15.36 (DA1), IC18.27 (DA1); also elsewhere on the board
PA2: IC15.35 (DA2), IC18.26 (DA2); also elsewhere on the board
PA3: IC15.34 (DA3), IC18.25 (DA3); also elsewhere on the board
PA4: IC15.33 (DA4), IC18.24 (DA4); also elsewhere on the board
PA5: IC15.32 (DA5), IC18.23 (DA5); also elsewhere on the board
PA6: IC15.31 (DA6), IC18.22 (DA6); also elsewhere on the board
PA7: IC15.30 (DA7), IC18.21 (DA7); also elsewhere on the board
PB0: J3.8; also elsewhere on the board
PB1: J3.7; also elsewhere on the board
PB2: J3.6; also elsewhere on the board
PB3: T2.1 (D); also elsewhere on the board
PB5: J9.2; also elsewhere on the board
PHI1: IC15.22 (CLOCK), IC18.15 (CLOCK); also elsewhere on the board
SOUND_OUT: C7.2, IC16.3 (+), J10.R1, J10.T, R46.2; also elsewhere on the board
VID_COMP: J11.1; also elsewhere on the board
~RESET: IC15.23 (~RESET), IC18.16 (~RESET); also elsewhere on the board

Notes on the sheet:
NOTE: With certain AY-39xx sound chips, when two keys in the same matrix row are pressed together, no key is registered, because the voltage drop is too low to be detected as logical 0. The diodes D4-D12 are meant to prevent that. Solder jumpers are also provided for the chips that don't need the d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
KBD_COL6
KBD_COL4
KBD_ROW0
KBD_ROW2
KBD_COL0
Alternative to AY-3-8910
KBD_COL3
KBD_ROW1
KBD_COL7
KBD_COL1
KBD_COL5
KBD_COL2

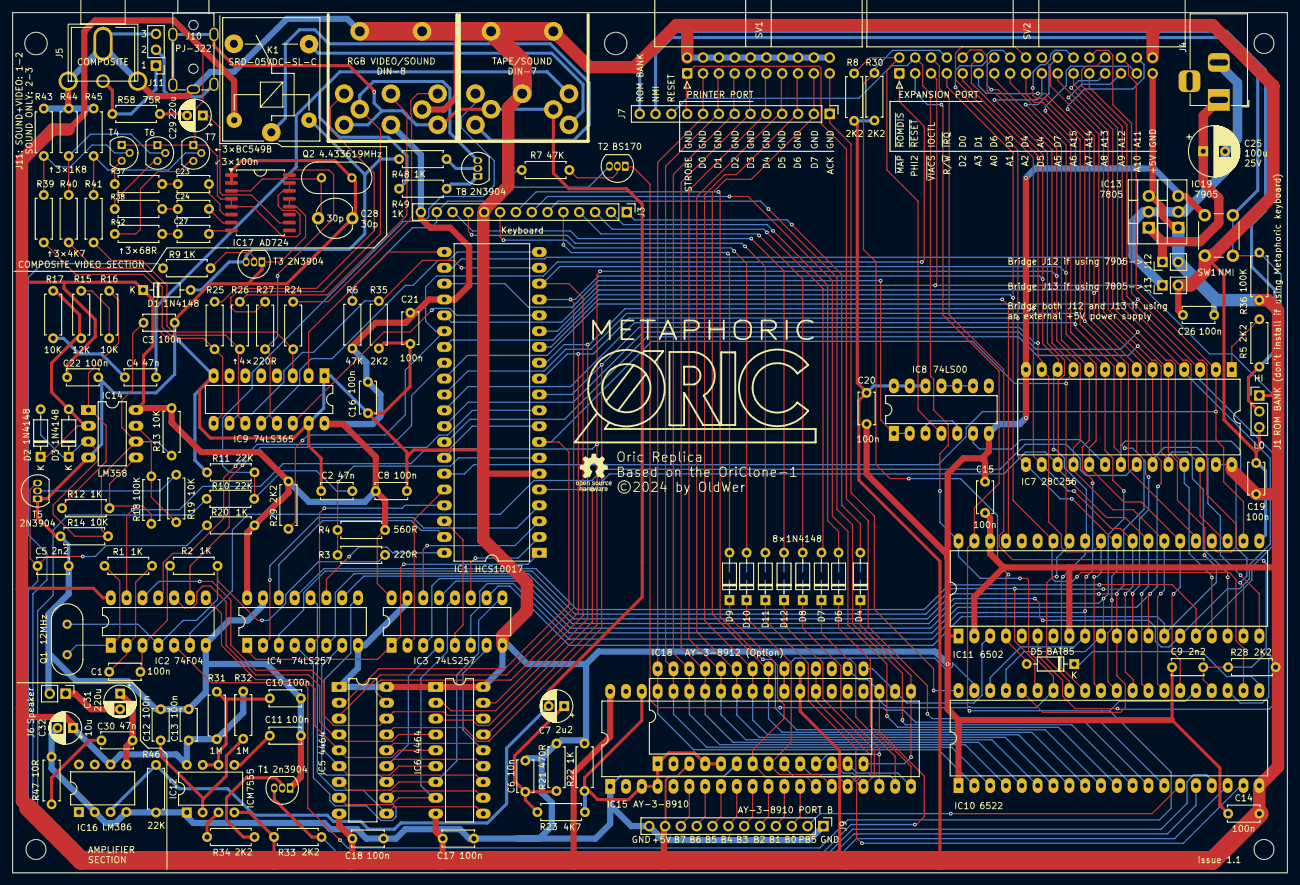
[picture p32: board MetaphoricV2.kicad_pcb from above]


Board: 2 copper layers, 204.5 x 138.0 mm, 148 parts (8 on the bottom side), 177 nets.

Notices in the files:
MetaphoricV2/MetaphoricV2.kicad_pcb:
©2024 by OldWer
